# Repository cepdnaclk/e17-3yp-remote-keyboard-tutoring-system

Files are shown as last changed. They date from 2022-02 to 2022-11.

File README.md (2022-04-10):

# Remote Keyboard Tutoring System

[](https://youtu.be/UrKorkKD-kg)

## Table of Contents
  - [Remote Keyboard Tutoring System](#remote-keyboard-tutoring-system)
  - [Table of Contents](#table-of-contents)
  - [Problem Overview](#problem-overview)
  - [Already Existing Approaches](#already-existing-approaches)
  - [Our Solution](#our-solution)
  - [Solution Architecture](#solution-architecture)
  - [Backend](#backend)
  - [Hardware Functionalities](#hardware-functionalities)
  - [Planned Features](#planned-features)
  - [Security Aspects](#security-aspects)
  - [Proposed Timeline](#proposed-timeline)
  - [Estimated Budget](#estimated-budget)
  - [Feedback](#feedback)
  - [Related Links](#related-links)

## Problem Overview

Piano is the most admired musical instrument so far. Over 25% of the world population fancy playing it. Yet not everyone is fortunate to learn from the best. This has fabricated a vast difference in the skill level of people who are playing the piano. The reason would be that most of the experts in the field lives in either the western hemisphere or east Asia. Even local experts aren't scattered throughout the island. So most of them tend to make use of the online procedures to teach piano. The current online methods would be using a platform like zoom and an app that simulates what one plays from his instrument.  Or else the student self learns just using an online app or tutorials. This hasn't shown profound results since the teacher or the student has problems when showing what he's playing on the piano in real time. The accuracy of the app isn't acceptable and the relationship between the student and the teacher isn't sturdy like in a live class room. Following problems occur due to an absence of a well-established remote method to teach or lean piano.

* A piano player has to be subtle. Several skills like hand / eye coordination, finger patterns, timing should be handled precisely.

* If teacher uses the online video streaming method to show what he plays on his piano, he might have to use several accessories (Ex: One camera to show his hand coordination, one camera to show his postures, a quality mic).

* People with a great potential might give up due to current ineffective ways to learn piano / keyboard online or not having a professional piano player to learn from his current location of residence.

## Already Existing Approaches

When it comes to online piano tutoring apps there are many popular apps for self-learning. Some of the popular apps are:

* [Skoove](https://www.skoove.com/en)
* [Yousician](https://yousician.com/)
* [Simply piano](https://www.joytunes.com/simply-piano)
* [Online Pianist](https://www.onlinepianist.com/)

All of them uses simulated keyboards to show the notes that the leaner should play and most of them uses the phone mic to get inputs to the app and give feedback to the player. These aren’t very accurate at giving you feedback since they can’t accurately identify the notes just using the microphone. The above applications _do not focus on remote real-time teaching_.

However, there are systems called [Piano Player Systems](https://www.amromusic.com/player-piano-systems) (or self playing pianos) which sort of do implement the above mentioned functionality. One example would be the [PianoDisc Piano Player](https://pianodisc.com/). These systems are mainly based on Pianos and not Keyboard Synthesizers. Thus, not everyone is able to afford those. Even though these systems can be used for remote tutoring purpose, they are mainly designed for entertainment purpose.

## Our Solution

The solution we present is a web based system that can be attached to any keyboard synthesizer through a MIDI connector (Legacy or USB). Thus, the only requirement for the keyboard is MIDI support. Once our system is connected to the keyboard, the user can interactively learn, play or teach in combination with the web application that we provide. The user has to be logged in as either a typical user or an expert depending on the user's needs. Users can get connected to each other in the network and they can share their music with each other. Users can play shared music in their own keyboard and join to experts to learn remotely in real-time. The tutor can handle multiple students at a time. When the tutor plays on the keyboard, those notes will be displayed and played in the students keyboards simultaneously. Tutor can upload exercises and when a student plays incorrectly, the wrong key presses will be displayed to both the student and the tutor.

## Solution Architecture

Our system consists of two devices: the _Pocessing Unit_ and the _Visualizer Bar_ which is a composition of _Visualizer Blocks_.

Processing Unit             |  Visualizer Bar
:--------------------------:|:-------------------------:
|  

The **Processing Unit** handles all the data processing and remote communications. It has two MIDI interfaces (one for MIDI-in and the other for MIDI-out) as well as two USB-C ports. The other USB port is to connect the visualizer bar in.

The **Visualizer Bar** is where all the key press information will be displayed at. The bar has to be placed on the keyboard near the end where the key hinges are. We provide the visualizer bar as easy-to-connect blocks in order for our product to fit any kind of keyboard and to make our product portable. The three common keyboard sizes are 61-keys, 76-keys and 88-keys. Therefore, the blocks are such that it covers an octave. Since blocks might not cover the whole keyboard, we provide the visualizer bar as a whole for the most common keyboard sizes as well. The visualizer bar has a USB-C port at the right end to connect in to the processing unit. The visualizer blocks have magnetic ends to stay still when they're connected. Left end of a block has a female USB-C port and the right end has a male USB-C connection. The bar has RGB leds representing each key and they will lit according to the key presses.

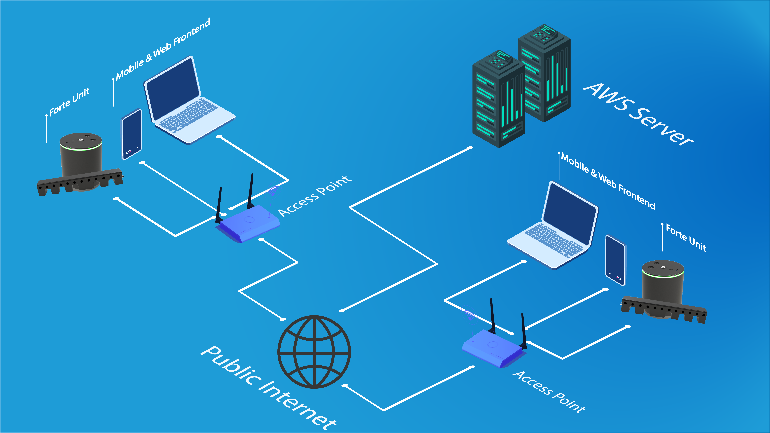
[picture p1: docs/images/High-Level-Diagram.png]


The above diagram shows an abstract diagram of how our system works.
Our solution consists of two main components: The Pocessing Unit and the Visualizer Bar 
The processing unit is connected to the keyboard via the MIDI interface and the processing unit is connected to the visualizer bar via a USB-C interface. The processing unit has inbuilt WI-FI as well as Bluetooth so the processing unit can directly connected to our server via a home router and exchange MIDI data with the server and with a another processing unit if they are connected in a same session. In order to communicate with the server we are going to implement a mobile as well as a web interface.

## Frontend

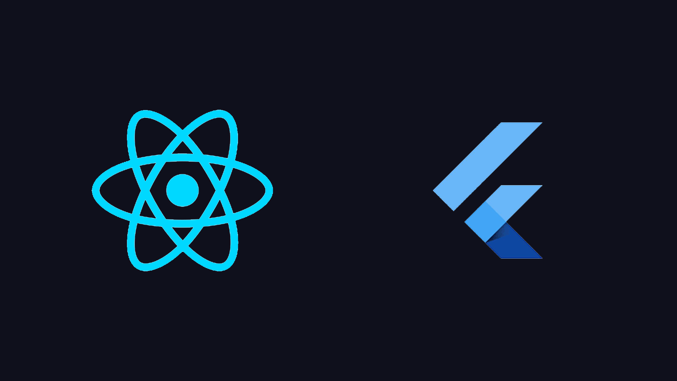
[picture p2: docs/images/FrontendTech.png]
Frontend-Technologies


For our frontend web platform would be implemented using React.js. React will assure a fast and easy development of the frontend since React provides lots of readymade components to use and React uses javascript it will be easier to coordinate with the backend as well. Other than that React apps can be made SEO friendly by making them server-side rendered rather than client-side rendered.
Our frontend mobile platform will be implemented using Flutter since it also provides a lot of components to use and Flutter performs well in a lot of mobile devices. Since Flutter uses Dart as the programming language we can use the same codebase for both ios and android applications.
[Click here](./web-app) to see what we have done up to now in the web frontend.
[Click here](./Mobile%20App/rkt_mobile) to see what we have done so far in the mobile frontend. 

## Backend

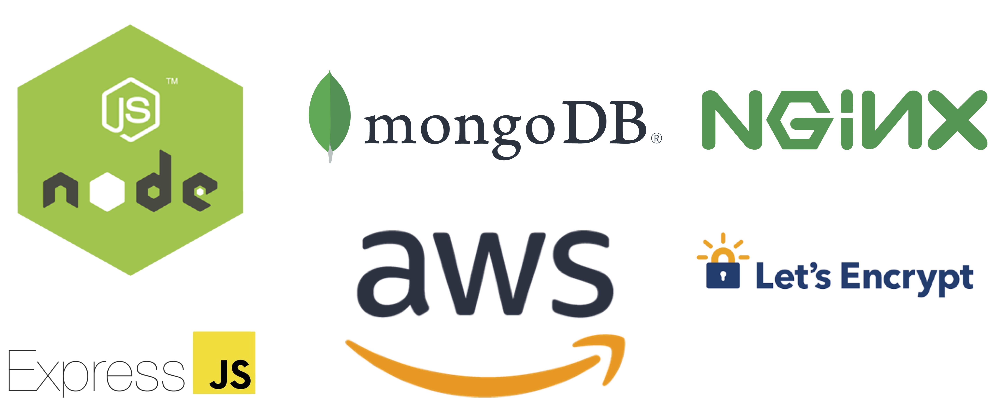
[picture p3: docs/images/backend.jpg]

Our backend computing platform would be Node.js along with express as the framework. It'll assist us in hadling multiple online requests and the working environment will be more effective and better-coordinated since javascript laguage is used in both frontend and backend development. MongoDB will be used as our database system. As the number of users for our product increase, it is very much practical to use MongoDB since it is very easy to scale up or down. MongoDB works on all types of cloud platforms. Since we'll be using aws to host our services MongoDB will be a great choice. NGINX is used as a reverse proxy so we can get access through http, https and Let's Encrypt is used to get free SSL certificates. All our backend services will be hosted using AWS services. An AWS EC2 instance is used run all the processes and AWS backup will be used to automate and manage backups. 

[click here](./server/src) to see what we have done so far.

## Hardware Functionalities

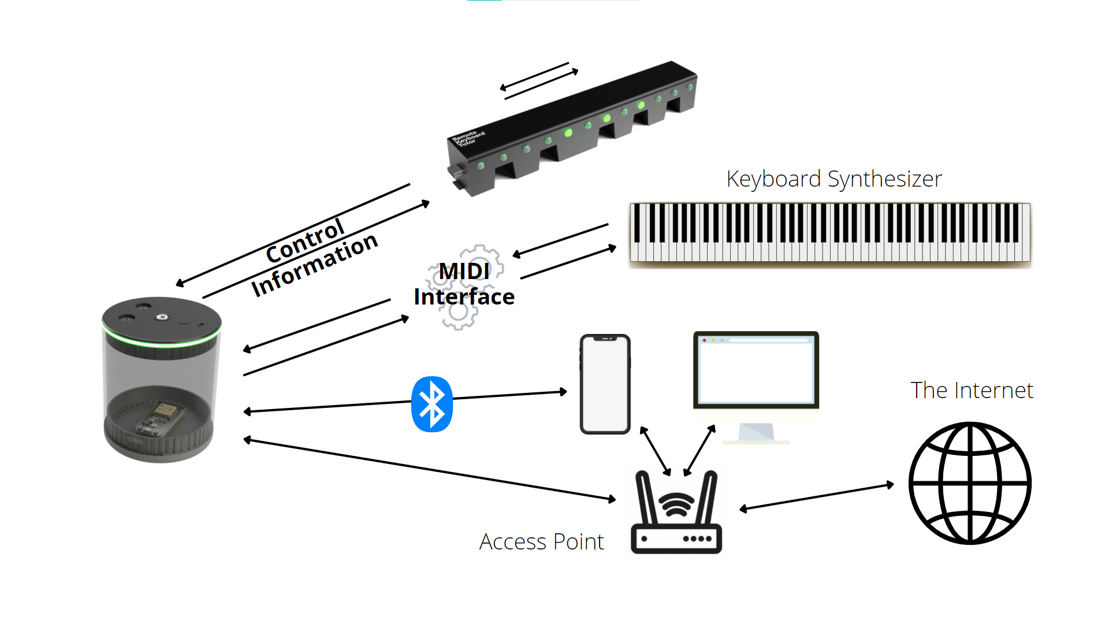
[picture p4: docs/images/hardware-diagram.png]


When it comes to hardware used in our embedded system, the brain of our processing unit is the **ESP32 Development board**. There are several reasons why we chose this board over other alternatives: built-in Wifi connectivity with 150Mbps data rate, integrated Bluetooth low energy (BLE) connectivity very small and compact board and the power consumption is less. As shown in the above high-level diagram, we need to have a MIDI interface in between the visualizer bar and the keyboard synthesizer for communicating with **MIDI messages** ([What is MIDI?](https://github.com/cepdnaclk/e17-3yp-remote-keyboard-tutoring-system/tree/main/Research/MIDI%20Technology)). The processing unit will be connected to Wifi as well as to the mobile phone via bluetooth. We use this BT connection for the offline helper as well as to authenticate to a Wifi router.

When MIDI messages arrive at the processing unit either from the user's keyboard or from remotely through the server, the microcontroller will process them and send control signals to the visualizer bar appropriately. The  communication between the visualizer bar and the processing unit will happen via an USB interface through a wired connection. The visualizer bar will also need to send signals to the processing unit because in order to light up the correct key on the keyboard, the processing unit needs to know the positional information of the particular visualizer block. So, before the user starts using the system he needs to do a very simple calibration procedure: play both the first note and the last note one after the other that the visualizer bar covers when the app prompts and thereafter the processing unit will memorize which block is where. In order to achieve this, the visualizer bar will also require a microcontroller. We will be using an arduino pro micro for this purpose.

## Planned Features

* Low latency real-time key press indication.
* Easy to setup / connect.
* The visualizer bar will be non-disturbing to the user and it will also add some aesthetics to the keyboard.
* The system will support any kind of non-standard keyboard as long as the keyboard has MIDI support.
* Students can easily find teachers available near their area.
* Classes can be scheduled through the application.
The web application allows teachers to upload exercises which will be played on student’s keyboard as MIDI so that the students can go along with and practise.
* Students can record what they’re playing and submit to the teacher in order to evaluate their work.
* An offline helper which can give assistance with the exercises.
* Efficient real-time Video & Audio Streaming for classes.
* Posture tracking for improving student's posture while playing.
* Finger tracking to check if the students are following the correct hand posture.

Current progress on implemented features can be seen [here](https://github.com/cepdnaclk/e17-3yp-remote-keyboard-tutoring-system/tree/main/web-app)

## Security Aspects

Cybersecurity of connected embedded system devices has always been important. Since our system also involves sharing private information through the internet like passwords and online payments, we have taken extra care to ensure the security of the system. The following diagram shows how we have designed our system to ensure the CIA triad.

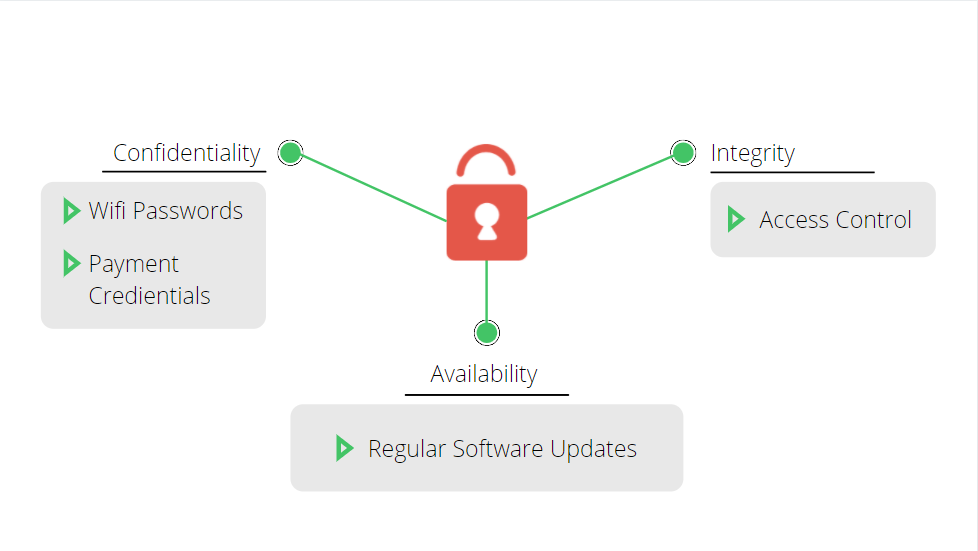
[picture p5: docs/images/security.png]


The following diagram shows our secure embedded system design process. The gray color path is the ideal embedded system design process that anyone would follow. In addition to that, we have added a security approach that'll happen in parallel with the embedded system design process. Starting from our concept of operations, we will do a threat analysis while collecting the functional requirements to analyze the potential attacks that the system may be subjected to when deployed. The next step is to specify how our demand measures the security requirements of the system. Once we have the security requirements, we will start developing the security approach after some rounds of evaluations.

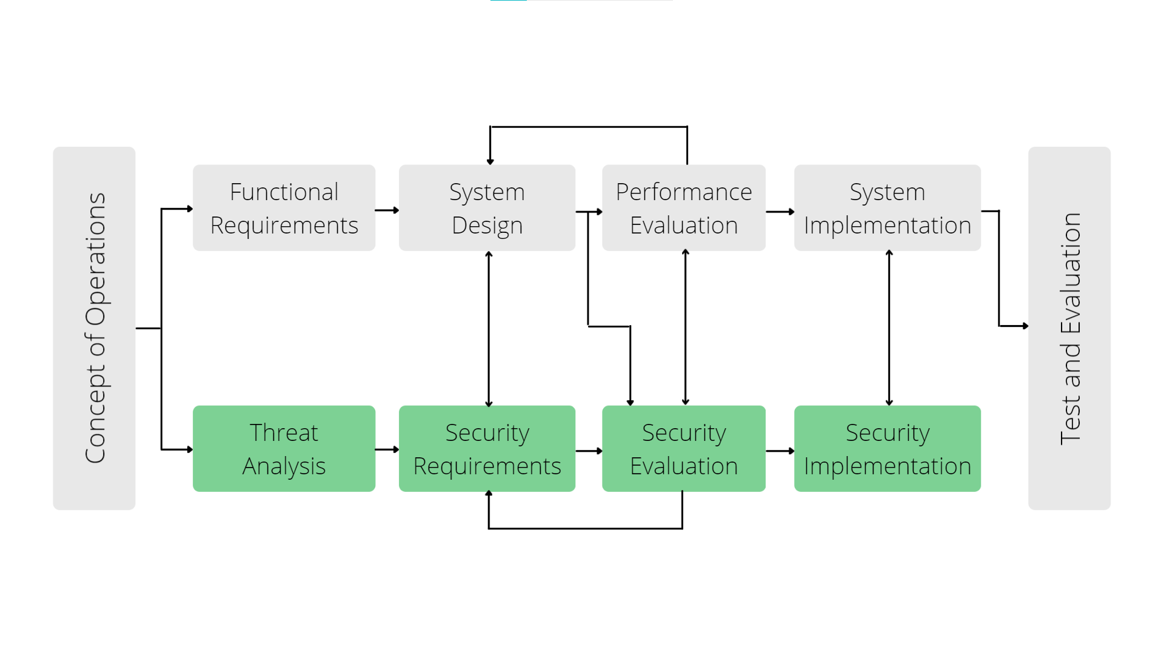
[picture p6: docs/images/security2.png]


## Proposed Timeline

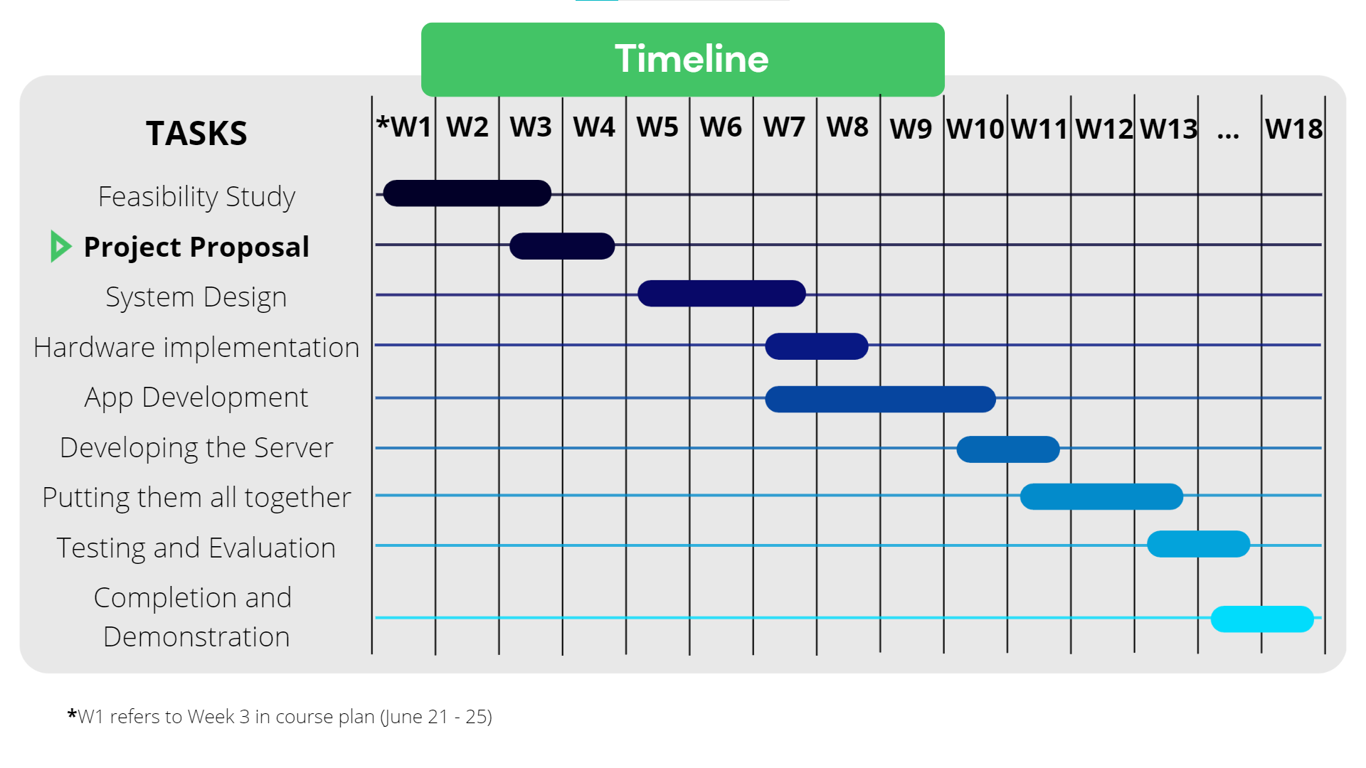
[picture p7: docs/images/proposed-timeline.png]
Proposed Timeline


## Estimated Budget

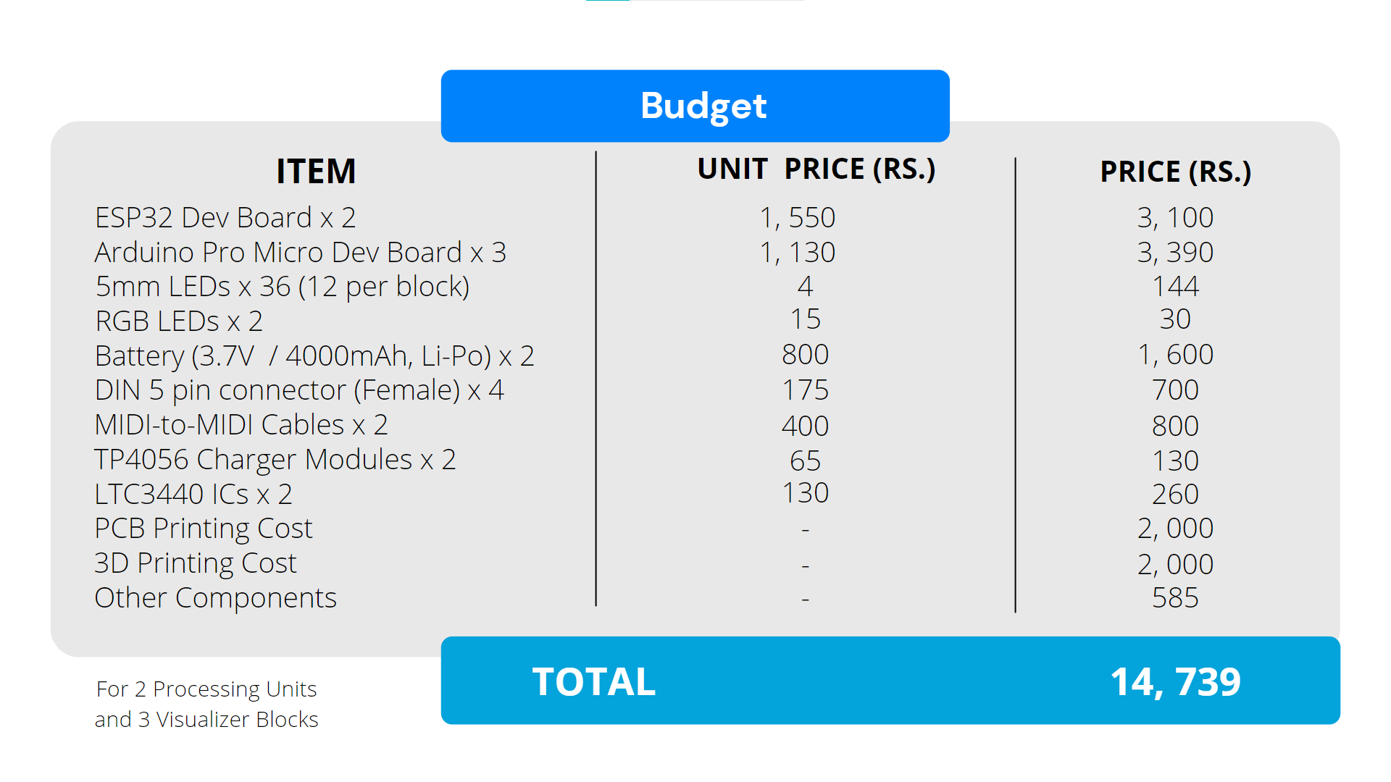
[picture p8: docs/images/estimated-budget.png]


## Feedback

✨ If you have any questions or suggestions for improvement regarding our project, feel free to share them [here](https://padlet.com/sathiiii/RKT_Discussion).✨

## Related Links

[University of Peradeniya](https://www.pdn.ac.lk/academics/academics.php/)

[Faculty of Engineering](http://eng.pdn.ac.lk/)

[Department of Computer Engineering](http://www.ce.pdn.ac.lk/)

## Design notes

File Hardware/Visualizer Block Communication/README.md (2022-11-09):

# Visualizer Block Communication

## Visualizer Block Schematic

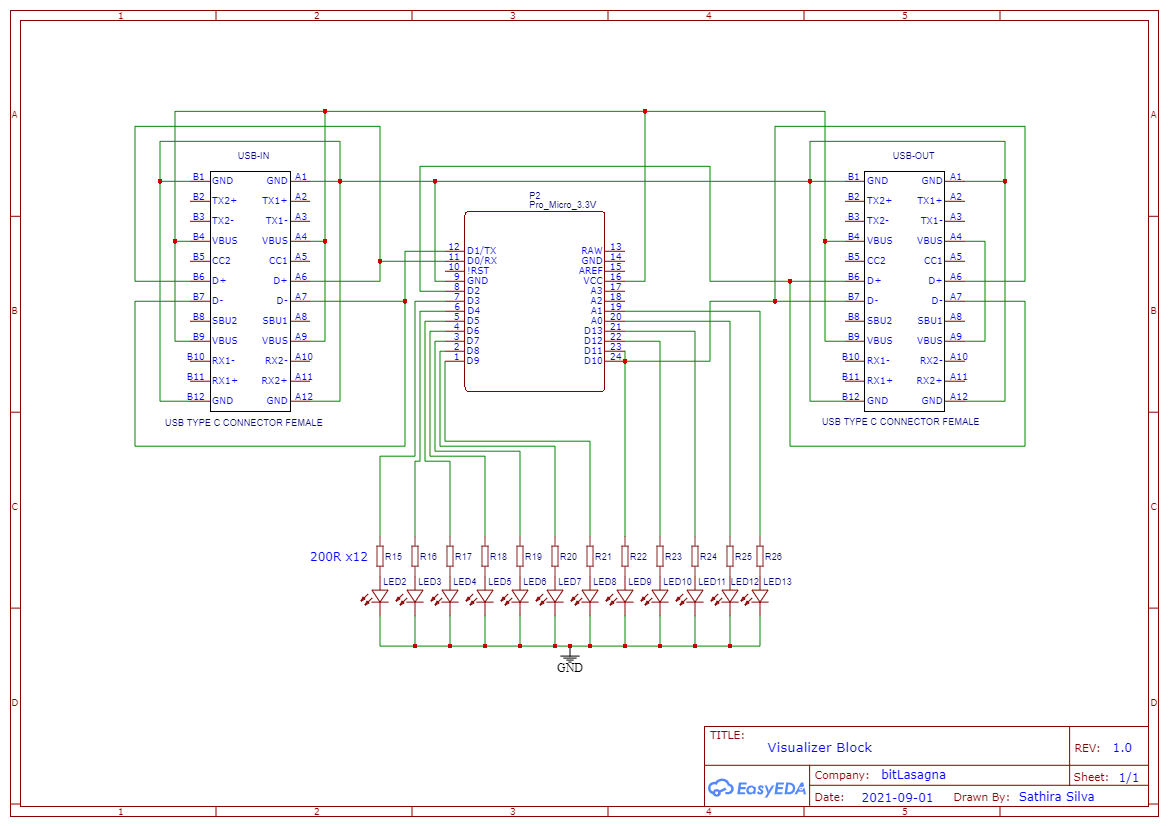
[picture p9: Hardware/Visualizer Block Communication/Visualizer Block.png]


All the operations in a Visualizer Block is handled by an **Arduino Pro Micro** inside. The reason for using an Arduino Pro Micro is that they come as two versions: 3.3V and 5V. Since the ESP32's working voltage is 3.3V, Arduino Pro Micro 3.3V will be compatible to communicate with it serially. Also, it consumes less power and the development board does not take much space. On the other hand, the serial port (pin 0 and pin 1) in Arduino Pro Micro is independent of the USB-Serial port that is used to communicate with PC. Therefore, we can use pin 0 and pin 1 for the Visualizer Block - Visualizer Block communication with no trouble since it won't interfere with the USB-Serial port.

The Arduino Pro Micro has 20 digital I/O pins. Therefore, it is more than enough to utilize 12 outputs for the 12 LEDs corresponding to the 12 different notes in an octave (C, C#, D, D#, E, F, F#, G, G#, A, Bb, B).

Unfortunately, the Pro Micro provides only one UART port. But we need two of them to communicate with each other. Therefore, we use the digital pins 3 as TX and 10 as RX with the **Arduino SoftwareSerial** library to replace the functionality.

## Communication

The communication between a Visualizer Block and another Visualizer Block or between a Visualizer Block and the processing unit is done **serially** via **UART communication protocol**.

UART, which stands for Universal Asynchronous Reception and Transmission, is a simple serial communication protocol that allows the host (Arduino Pro Micro or ESP32 in our case) to communicate with serial devices.

UART supports bidirectional, asynchronous and serial data transmission.

Before the UART device can send data, the transmitting device converts the data bytes to bits. After converting the data into bits, the UART device then splits them into **packets** for transmission. Each packet contains a start bit, a data frame, parity bit, and the stop bit. The data frame is usually 8 bits long. The following diagram shows an example data packet:



The following diagram shows how the data transmission and framing happens in UART communication protocol.

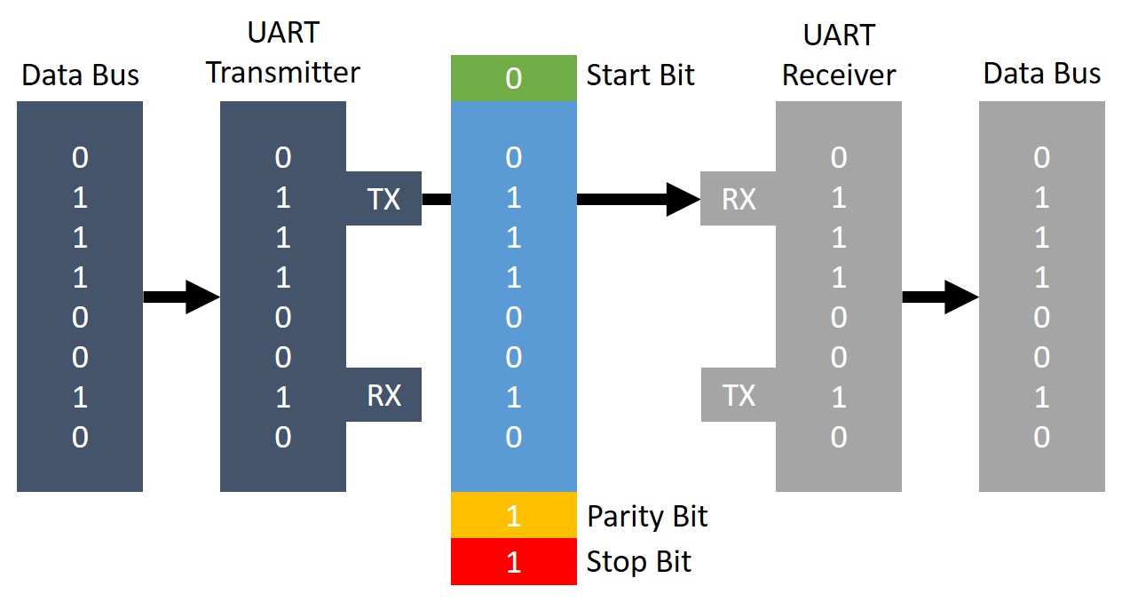
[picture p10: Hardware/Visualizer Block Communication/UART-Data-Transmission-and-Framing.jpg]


One advantage of UART is that only 2 wires are needed for the communication between master and slave device, because there is no need for a clock line and like SPI communication, there is also no slave select line. The 2 lines are: TX (transmission) and RX (reception).

### Our own communication protocol

The following diagram dipicts how the hardware communicates with each other.

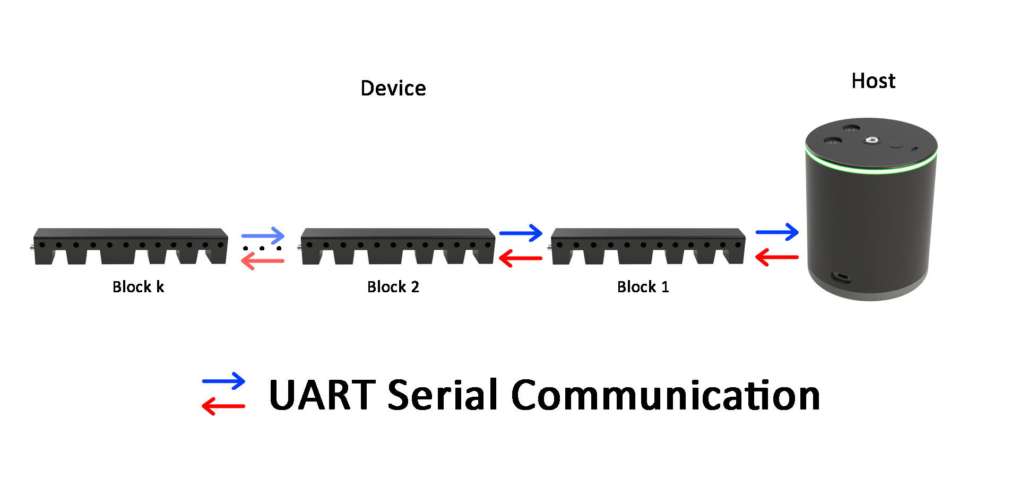
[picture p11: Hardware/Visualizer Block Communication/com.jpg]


We've made our own communication protocol to communicate with the Visualizer Blocks. The Processing Unit is referred to as the **Host** and the Visualizer Bar is referred to as the **Device**.

As shown in the above diagram, there are two types of communication: **Host-Device** communication and **Device-Device** communication. During data transmission, the sender will be the master and the reciever will the slave since in UART communication there'll always be 1 master and 1 slave. So, the transmissions are done in a **daisy chain** (several devices linked together serially) fashion.

When MIDI messages are recieved by the Processing Unit, it processes them and sends serial data packets to the appropriate Visualizer Block. The data packet won't arrive at the particular block directly, instead the packet will travel through all the blocks until the packet finds it's destination Visualizer Block.

Therefore, there's a need to define different kind of data packets (bit strings) that is responsible for different tasks. The reciever's id (or an address) and/or the sender's id also needs to be encapsulated in a data packet.

The types of packets we're using for host-device and device-device communication are as following:
1. Device notify packets.
2. Device discovery packets.
3. Host notify packets.
4. Control information packets.

To indicate which packet is which, we will include two bits (for now) of information to store the **action** of the packet.

<table>
  <tr>
    <th>action</th>
    <th>Description</th>
  </tr>
  <tr>
    <td>00</td>
    <td>Device Notify</td>
  </tr>
  <tr>
    <td>01</td>
    <td>Device Discovery</td>
  </tr>
  <tr>
    <td>10</td>
    <td>Host Notify</td>
  </tr>
  <tr>
    <td>11</td>
    <td>Control Information</td>
  </tr>
</table>

A packet in general will be as follows:

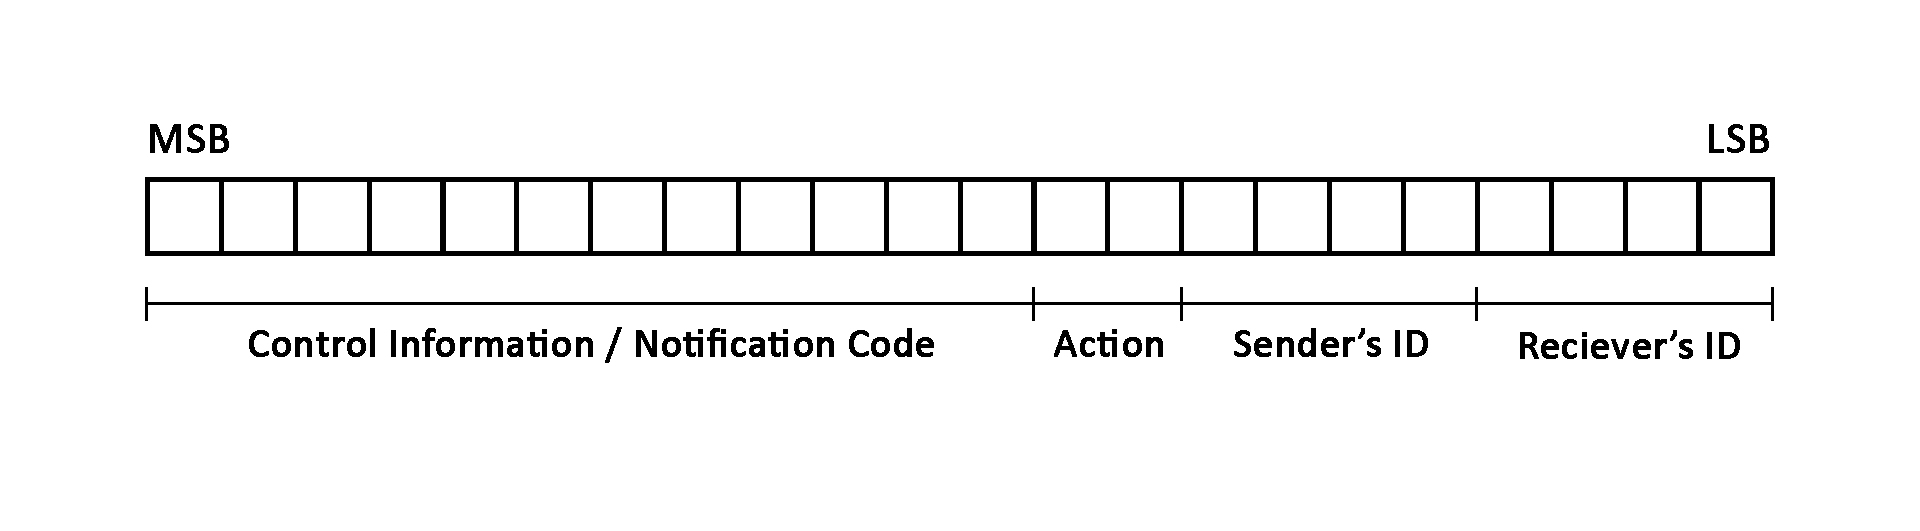
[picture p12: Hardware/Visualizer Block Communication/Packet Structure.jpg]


Note that the visualizer blocks will always send **Device Notify** packets indicating that it is communicating with another visualizer block unless it is the directly connected block to the processing unit. Otherwise, the visualizer block can send a **Host Notify** packet since it can directly communicate with the processing unit. However, if the Device Discover (which the following sections describe in detail) phase is not completed yet, the visualizer block that's directly connected to the processing unit will send a **Device Notify** packet to the host since the visualizer block doesn't know that it has a direct connection to the host, yet. This also makes the host to know which block is the directly connected one.

**When the processing unit is powered on**, it will wait until the visualizer bar to be connected. The processing unit waits for a **Device Notify: Connected** packet (i.e. until there's an available visualizer bar connection. When a visualizer block is connected, it sends a **Device Notify: Connected** packet to the device at the right side of it). The LED ring will flash periodically to indicate that the visualizer bar needs to be connected. When it is connected to the visualizer bar, the LED ring will be turned off to indicate that the **Device Discovery** is on progress. When the processing unit recieves a Device Notify: Connected packet, it sends a **Device Discovery** packet containing it's ID (zero) and the destination id (the visualizer block id) set to be 1 initially.

### The Device Discovery Phase

The device discovery happens as following:
1. The processing unit sends a device discovery packet containing the block_id (reciever's id) initialized to 0, to the visualizer bar. The sender's id will be zero to indicate that it's the processing unit that sends the packet.
2. The very first visualizer block that is directly connected to the processing unit will receive the packet and will assign the block_id to itself. Then it'll set the sender's id as the block_id that it just assigned, increment the block_id and will send another device discovery packet to the next visuzlier block that is connected to it.
3. So on and so forth this will happen until the packet reaches the last visualizer block. Because of the **Device Notify: Connected** packets that were initially sent. The last block knows that nothing is connected to the left side of it and thus it is the last block. Therefore, this block will send a **Host Notify: Discovery Finished** packet with sender's id being the final value of the block id (block id of the last visualizer block) and the reciever's id being zero back to the processing unit.

**Host Notify** packets won't be modified by any of the recieving devices and will be forwarded until the packet reaches the processing unit.

When the host recieves the **Host Notify: Discovery Finished** message, it is ready for the next stage: **Callibration**.

### Callibrating the Visualizer Bar

Callibrating pretty simple, the LED ring will flash twice periodically when the Device Discovery is finished, indicating that the user needs to press the first key that the first visualizer block (in terms of the block id, the last visualizer block) covers.

Then, the processing unit will map each key to each visualizer block and store those information. So, when a MIDI message arrives at the processing unit, it can process the message and find which block covers that particular key in the MIDI message and send the Control Information packet to that Visualizer Block.

**NOTE:** If the visualizer block positions have been changed, the user can recallibrate by tapping the command button twice on the processing unit.

After the callibration is done, the system is ready.

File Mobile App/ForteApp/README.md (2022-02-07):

# Forte App

## Getting Started

This project is a starting point for a Flutter application.

A few resources to get you started if this is your first Flutter project:

- [Lab: Write your first Flutter app](https://flutter.dev/docs/get-started/codelab)
- [Cookbook: Useful Flutter samples](https://flutter.dev/docs/cookbook)

For help getting started with Flutter, view our
[online documentation](https://flutter.dev/docs), which offers tutorials,
samples, guidance on mobile development, and a full API reference.

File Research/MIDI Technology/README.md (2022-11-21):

# What's MIDI?

- MIDI - Musical Instrument Digital Interface
- A standard protocol for communication between computers and musical instruments. 
- Sends series of **messages** which are intepretted by a MIDI instrument.

## MIDI messages
- Made up of an 8-bit **status byte** (or **command byte**) which is generally followed by 1 or 2 **data bytes**.
- Command byte: tells what type of message is being sent.
- Data bytes: actual data that is sent with the command byte.
- Two types of MIDI messages: *System messages*, *Channel messages*.

- Channel -> an independent path over which messages travel to their destination.
- A MIDI device has 16 channels.
- Channel messages -> apply to a specific channel, channel number is included in the status byte.
- Channel Messages may be further classified as being either *Channel Voice Messages*, or *Mode Messages*.
- Channel Voice Messages: carries musical performance data.

## Channel Voice Messages

Categories: Note On, Note Off, Polyphonic Key Pressure, Channel Pressure, Pitch Bend Change, Program Change, and the Control Change messages.

- MIDI **data bytes** range from 0 to 127 (MSB is always 0).
- MIDI **command byte** ranges from 128 to 255 (MSB is always 1).
- Two types of bytes are differentiated by the MSB.
- First half of the command byte (three bits after MSB) -> sets the type of command.
- Last half of the command byte -> sets the channel number.

## MIDI Commands



10000000 (128) = note off</br>
10010000 (144) = note on</br>
10100000 (160)  = aftertouch</br>
10110000 (176) = continuous controller</br>
11000000 (192) = patch change</br>
11010000 (208) = channel pressure</br>
11100000 (224) = pitch bend</br>

### Note On

- Sent when a key is pressed.
- Consists of two pieces of info: which key was pressed (**note**) and how fast it was pressed (**velocity**).
- **Note** is a number from 0 to 127. Middle C (C4) is 60.
- **Velocity** is a number from 0 to 127. Describes volume of the note.
(For some voices, different velocities create different **timbres**.)

### Note Off

- Sent when a key is released.
- Also contain **note** information to ensure that it is signalling the end of the right note.
- Sometimes a note off may contain velocity information too.

### Aftertouch

- The amount of pressure applied to a note.
- Sent when a key is pressed.
- Ranges from 0 to 127.

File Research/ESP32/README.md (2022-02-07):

# ESP-32 Development Board

[Official Documentation](https://docs.espressif.com/projects/esp-idf/en/latest/esp32/)

## Introduction

ESP32 is a system on a chip that integrates the following features:

* Wi-Fi (2.4 GHz band, 150.0 Mbps data rate with HT40)
* Bluetooth (BLE - Bluetooth Low Energy and Bluetooth Classic)
* Dual high performance Xtensa® 32-bit LX6 CPU cores  running at 160 or 240 MHz
* Ultra Low Power co-processor
* Flash memory (4 MB)
* 32-bit SRAM
* Multiple peripherals
* Security: hardware accelerators for AES and SSL/TLS
* Arduino IDE compatible
* Low Power: ensures that you can still use ADC conversions, for example, during deep sleep

Powered by *40 nm technology*, ESP32 provides a robust, highly integrated platform, which helps meet the continuous demands for **efficient power usage**, **compact design**, **security**, **high performance**, and **reliability**.

The ESP32 can be programmed in different programming environments, including:

* Arduino IDE
* Espressif IDF (IoT Development Framework)
* Micropython
* JavaScript
* LUA

Espressif provides basic hardware and software resources to help application developers realize their ideas using the ESP32 series hardware. The software development framework by Espressif is intended for development of Internet-of-Things (IoT) applications with Wi-Fi, Bluetooth, power management and several other system features.

## ESP32 Peripherals

The ESP32 peripherals include:

* 18 Analog-to-Digital Converter (ADC) channels
* 3 SPI interfaces
* 3 UART interfaces
* 2 I2C interfaces
* 16 PWM output channels
* 2 Digital-to-Analog Converters (DAC)
* 2 I2S interfaces
* 10 Capacitive sensing GPIOs

The ADC (analog to digital converter) and DAC (digital to analog converter) features are assigned to specific static pins. However, you can decide which pins are UART, I2C, SPI, PWM, etc – you just need to assign them in the code. This is possible due to the ESP32 chip’s multiplexing feature.

Although you can define the pins properties on the software, there are pins assigned by default as shown in the following figure (this is an example for the ESP32 DEVKIT V1 DOIT board with 36 pins – the pin location can change depending on the manufacturer).



Additionally, there are pins with specific features that make them suitable or not for a particular project. The following table shows what pins are best to use as inputs, outputs and which ones you need to be cautious.

The pins highlighted in green are OK to use. The ones highlighted in yellow are OK to use, but you need to pay attention because they may have an unexpected behavior mainly at boot. The pins highlighted in red are not recommended to use as inputs or outputs.

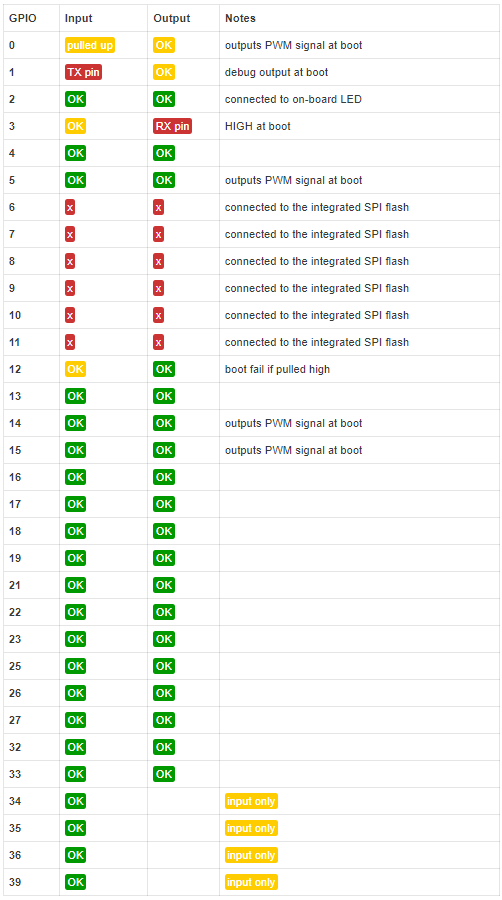
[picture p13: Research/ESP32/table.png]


GPIOs 34 to 39 are GPIs – input only pins. These pins don’t have internal pull-up or pull-down resistors. They can’t be used as outputs, so use these pins only as inputs:
* GPIO 34
* GPIO 35
* GPIO 36
* GPIO 39

## Power Requirements

The ESP32 Board operates between 2.2V to 3.6V. But we supply 5V from Micro-USB port. For 3.3V there is already an LDO voltage regulator to keep the voltage steady at 3.3V. ESP32 can be powered using Micro USB port and VIN pin (External Supply Pin).

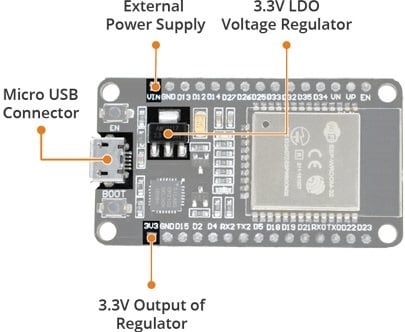
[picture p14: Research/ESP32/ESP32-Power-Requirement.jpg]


The power required by ESP32 is 600mA, as ESP32 pulls as much as 250mA during RF transmissions. During boot or wifi operation it’s drawing more than 200mA current. Thus supply power from Micro-USB Cable is not enough for ESP32 Board when we are adding multiple sensors or modules to the Board. This is because Computer USB port can provide less than 500mA of current.

## ESP-IDF (IoT Development Framework)

ESP-IDF is Espressif’s open-source official IoT Development Framework for the ESP32 series. It provides a self-sufficient SDK for any generic application development on these platforms, using programming languages such as C and C++. ESP-IDF supports a large number of software components, including RTOS, peripheral drivers, networking stack, various protocol implementations, and helpers for common application use-cases.

The framework also consists security of features such as hardware-backed security features, such as flash encryption and secure boot, cryptographic accelerator support for RSA, SHA and AES, libsodium and micro-ecc cryptographic libraries.

ESP-IDF supports IDEs such as Visual Studio Code ([Visual Studio Code Extension](https://github.com/espressif/vscode-esp-idf-extension), [Quick User Guide for the ESP-IDF VS Code Extension](https://youtu.be/Lc6ausiKvQM)) and Eclipse ([Eclipse IDE plugin](https://github.com/espressif/idf-eclipse-plugin)).

## ESP-IDF vs Arduino-ESP32

Arduino-ESP32 library is just a wrapper around the esp-idf mainly simplifying things and making it integrated with the design paradigms of arduino as a whole.

One can use the arduino version for the same reason that he would use arduino as a whole, namely for its low barrier to entry, extensive ecosystem/support, and ease of use. But he's not going to get the best performance, have the most maintainable/extensible code, or be able to take full advantage of the peripherals.

Firstly, arduino kind of pushes you in the wrong direction for serious embedded development, artificially confining you to a **setup and loop function**, when in reality it should be more focused on **compartmentalization of function into a task based application**. This is essentially what arduino-esp32 does under the hood, but you wouldn't know unless started to look into the idf yourself.

Secondly, being able to work directly with the idf means that you can actually understand errors that you get when you start combining peripherals or calling idf functions. You can call idf functions in arduino-esp32, but it is much easier to directly use the idf, be familiar with the api reference, and work directly with the source than having to translate everything through the wrapper functions when debugging something.

Thirdly, the idf runs **freeRTOS (free Real-Time Operating System)** (an operating system that runs code as **tasks**) which is pretty widespread in embedded systems, so the techniques and knowledge you gain will translate pretty well to other MCUs if you ever work with any others. This is where the idea of having **tasks and message passing between tasks** as opposed to a "**superloop**" comes from. You could do a super loop just as well in freeRTOS, but it is really designed to be more task based. Further, the idf has the design pattern of components which allow you to split off functionality into their little compartments, allowing large projects to be much easier to organize.

[~source](https://www.reddit.com/r/esp32/comments/dk3rsn/why_idf_vs_arduino_ide/)

## FreeRTOS Architecture

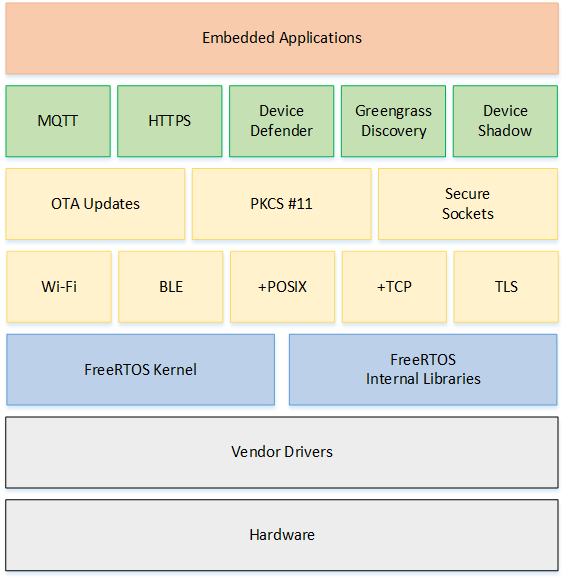
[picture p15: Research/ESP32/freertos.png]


## FreeRTOS Kernel Fundamentals

The Espressif Internet Development Framework (ESP-IDF) uses FreeRTOS to make better use of the two high speed processors and manage the numerous built-in peripherals. It is done by creating tasks.

The FreeRTOS kernel provides,
* A multitasking scheduler.
* Multiple memory allocation options (including the ability to create completely statically-allocated systems).
* Intertask coordination primitives, including task notifications, message queues, multiple types of semaphore, and stream and message buffers.

The FreeRTOS kernel is designed to be small, simple, and easy to use. A typical RTOS kernel binary image is in the range of 4000 to 9000 bytes.

### Kernel Memory Allocation

The RTOS kernel needs RAM each time a task, queue, or other RTOS object is created. The RAM can be allocated:

* Statically at compile time.
* Dynamically from the RTOS heap by the RTOS API object creation functions.

When RTOS objects are created dynamically, using the standard C library malloc() and free() functions is not always appropriate for a number of reasons:

* They might not be available on embedded systems.
* They take up valuable code space.
* They are not typically thread-safe.
* They are not deterministic.

For these reasons, FreeRTOS keeps the memory allocation API in its **portable layer**. The portable layer is outside of the source files that implement the core RTOS functionality, so you can provide an application-specific implementation appropriate for the real-time system you're developing. When the RTOS kernel requires RAM, it calls pvPortMalloc() instead of malloc(). When RAM is being freed, the RTOS kernel calls vPortFree() instead of free().

### Application Memory Management

When applications need memory, they can allocate it from the FreeRTOS heap. FreeRTOS offers several heap management schemes that range in complexity and features. You can also provide your own heap implementation.

The FreeRTOS kernel includes five heap implementations:

**heap_1**
Is the simplest implementation. Does not permit memory to be freed.

**heap_2**
Permits memory to be freed, but not does coalesce adjacent free blocks.

**heap_3**
Wraps the standard malloc() and free() for thread safety.

**heap_4**
Coalesces adjacent free blocks to avoid fragmentation. Includes an absolute address placement option.

**heap_5**
Is similar to heap_4. Can span the heap across multiple, non-adjacent memory areas.

## Hello World

The following is the structure of ESP-IDF:

>+--esp-idf<br>
&nbsp;&nbsp;&nbsp;&nbsp;	|<br>
&nbsp;&nbsp;&nbsp;&nbsp;	+ - - components<br>
&nbsp;&nbsp;&nbsp;&nbsp;	|<br>
&nbsp;&nbsp;&nbsp;&nbsp;	+ - - docs<br>
&nbsp;&nbsp;&nbsp;&nbsp;	|<br>
&nbsp;&nbsp;&nbsp;&nbsp;	+ - - examples<br>
&nbsp;&nbsp;&nbsp;&nbsp;	|<br>
&nbsp;&nbsp;&nbsp;&nbsp;	+ - - make<br>
&nbsp;&nbsp;&nbsp;&nbsp;	|<br>
&nbsp;&nbsp;&nbsp;&nbsp;	+ - - tools<br>

The components directory holds all the 'C' code for the ESP32. It contains all the **components** that make up the ESP32. It includes Drivers for numerous peripherals, the bootloader, bt(bluetooth), freeRTOS etc.

### The Includes

```C
#include <stdio.h>
#include "freertos/FreeRTOS.h"
#include "freertos/task.h"
#include "esp_system.h"
#include "esp_log.h"
```

* freertos/FreeRTOS.h : Inclusion of this sets configuration required to run freeRTOS on ESP32.
* freertos/task.h: The tasks as you can guess provide the multitasking functionality.
* esp_system.h: This inclusion configures the peripherals in the ESP system. Think of it as system initialization. It's like setting up all the components of your bike, before you could fire the engine!
* esp_log.h: This is the logging library. It's used to log information to the serial port.

### The main() function

Unlike normal FreeRTOS tasks (or embedded C main functions), the **app_main** task is allowed to return. If this happens, The task is cleaned up and the system will continue running with other RTOS tasks scheduled normally. Therefore, it is possible to implement app_main as either a function that creates other application tasks and then returns, or as a main application task itself. app_main is called from a task called main_task spawned in cpu_start.c.

```C
void app_main()
{
    nvs_flash_init();
    xTaskCreate(&hello_task, "hello_task", 2048, NULL, 5, NULL);
}
```

* **Initialize Flash: nvs_flash_init()**: Non-volatile storage (NVS) library is designed to store key-value pairs in flash. This API initialises the default NVS partition.
* **xTaskCreate**: Creates a new task and adds it to the list of tasks that are ready to run. Following is the function prototype:
<br>BaseType_t xTaskCreate(TaskFunction_t pvTaskCode,
&nbsp;&nbsp;&nbsp;&nbsp;&nbsp;&nbsp;&nbsp;&nbsp;const char * const pcName,
&nbsp;&nbsp;&nbsp;&nbsp;&nbsp;&nbsp;&nbsp;&nbsp;configSTACK_DEPTH_TYPE usStackDepth,
&nbsp;&nbsp;&nbsp;&nbsp;&nbsp;&nbsp;&nbsp;&nbsp;void *pvParameters,
&nbsp;&nbsp;&nbsp;&nbsp;&nbsp;&nbsp;&nbsp;&nbsp;UBaseType_t uxPriority,
&nbsp;&nbsp;&nbsp;&nbsp;&nbsp;&nbsp;&nbsp;&nbsp;TaskHandle_t *pxCreatedTask);
<br>**pvTaskCode**: Pointer to the task entry function.
<br>**pcName**: A descriptive name for the task. This is mainly used to facilitate debugging, but can also be used to obtain a task handle.
<br>**usStackDepth**: The number of words (not bytes!) to allocate for use as the task's stack. For example, if the stack is 16-bits wide and usStackDepth is 100, then 200 bytes will be allocated for use as the task's stack. As another example, if the stack is 32-bits wide and usStackDepth is 400 then 1600 bytes will be allocated for use as the task's stack.
<br>**pvParameters**: A value that is passed as the paramater to the created task. If pvParameters is set to the address of a variable then the variable must still exist when the created task executes - so it is not valid to pass the address of a stack variable.
<br>**uxPriority**: The priority at which the created task will execute.
<br>**pxCreatedTask**: Used to pass a handle to the created task out of the xTaskCreate() function. pxCreatedTask is optional and can be set to NULL.

### The hello_task()

The function that is called from the task created above is a simple function as shown below. It simply prints the string to the UART. The Print stream is configured to the UART0 of the ESP32.

```C
void hello_task(void *pvParameter)
{
    printf("Hello world!\n");
    for (int i = 10; i >= 0; i--) {
        printf("Restarting in %d seconds...\n", i);
        // Delay a task for a given number of ticks.
        vTaskDelay(1000 / portTICK_RATE_MS);
    }
    printf("Restarting now.\n");
    fflush(stdout);
    // Software restart.
    esp_restart();
}
```

### The Complete Code

```C
#include <stdio.h>
#include "freertos/FreeRTOS.h"
#include "freertos/task.h"
#include "esp_system.h"
 
void hello_task(void *pvParameter)
{
    printf("Hello world!\n");
    for (int i = 10; i >= 0; i--) {
        printf("Restarting in %d seconds...\n", i);
        vTaskDelay(1000 / portTICK_RATE_MS);
    }
    printf("Restarting now.\n");
    fflush(stdout);
    esp_restart();
}
 
void app_main()
{
    nvs_flash_init();
    xTaskCreate(&hello_task, "hello_task", 2048, NULL, 5, NULL);
}
```

## Multitasking: Hello World with Blink

It is easy to accomplish that using the RTOS. The code below, creates two tasks. It can be thought of as these are two infinite (while) loops. _Whenever one enters delay state (vTaskDelay function), the other runs and vice-versa_. Since we are slow and ESP32 is fast, it switches between the tasks numerous times and we see both the tasks happening simultaneously.

```C
#include <stdio.h>
#include "freertos/FreeRTOS.h"
#include "freertos/task.h"
#include "esp_system.h"
// Allows to manage General Purpose I/O pins via simple and portable APIs.
#include "driver/gpio.h"
#include "nvs_flash.h"

#define BLINK_GPIO 2
 
void hello_task(void *pvParameter)
{
	while(1)
	{
	    printf("Hello world!\n");
	    vTaskDelay(100 / portTICK_RATE_MS);
	}
}

void blinky(void *pvParameter)
{
    gpio_pad_select_gpio(BLINK_GPIO);
    /* Set the GPIO as a push/pull output */
    gpio_set_direction(BLINK_GPIO, GPIO_MODE_OUTPUT);
    while(1) {
        /* Blink off (output low) */
        gpio_set_level(BLINK_GPIO, 0);
        vTaskDelay(1000 / portTICK_RATE_MS);
        /* Blink on (output high) */
        gpio_set_level(BLINK_GPIO, 1);
        vTaskDelay(1000 / portTICK_RATE_MS);
    }
}
 
void app_main()
{
    nvs_flash_init();
    xTaskCreate(&hello_task, "hello_task", 2048, NULL, 5, NULL);
    xTaskCreate(&blinky, "blinky", 512,NULL,5,NULL );
}
```

On FreeRTOS, tasks have an assigned priority which the scheduler uses to decide which task will run. High priority tasks ready to run will have preference over lower priority tasks, which means that as long as a higher priority task can run, a lower priority task will not have the CPU.

## Utilizing multiple cores

FreeRTOS tasks can be pinned to a specific core too. Note that, when we create a task with the xTaskCreate function, we are not specifying any particular core for it to run. So, FreeRTOS will run the task on the core that is free.

To know in which core a task is running, the **xPortGetCoreID()** function can be used.

Tasks can be pinned to a specific core using the **vTaskCreatePinnedToCore** function. This function takes exactly the same arguments of the xTaskCreate and an additional argument at the end to specify the core where the task should run.

```C
xTaskCreatePinnedToCore(
                    coreTask,   /* Function to implement the task */
                    "coreTask", /* Name of the task */
                    2048,       /* Stack size in words */
                    NULL,       /* Task input parameter */
                    0,          /* Priority of the task */
                    NULL,       /* Task handle. */
                    taskCore);  /* Core where the task should run */
```

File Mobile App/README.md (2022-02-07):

# forté Mobile App

## What we have done so far

These are the functions that we have added upto now to the the forté mobile app.

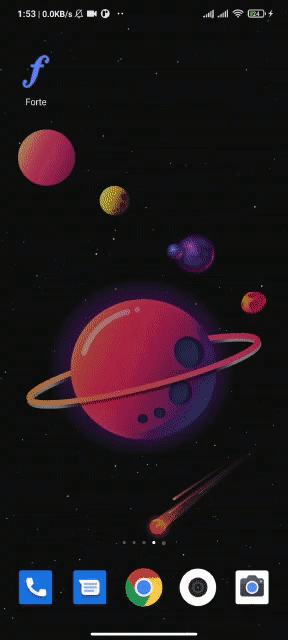
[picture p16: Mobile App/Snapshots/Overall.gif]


### ESP Provisioning



More details about esp provisioning can be found [here.](https://docs.espressif.com/projects/esp-idf/en/latest/esp32/api-reference/provisioning/wifi_provisioning.html)

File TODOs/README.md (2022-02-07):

# TODO List

Please make sure to update the list and mark the finished tasks.

- [x] Finish the repo documentation (initial).
- [x] Update the website information (initial).
- [x] Add a timeline section to the website such that our completed milestone can be displayed there.
- [ ] **First testing: Arduino MIDI read / write test.**
- [x] Update repo documentation: Solution Architecture.
- [x] Update repo documentation: Data flow + Generation of data + Visualizations.
- [x] Update repo documentation: Hardware functionalities.
- [x] Update repo documentation: Security aspects.
- [x] Update website: Add dropdown to navbar.
- [x] Update website: Data flow + Generation of data.
- [x] Update website: UI designs (placeholders).
- [x] Update website: Features (Each with placeholders for descriptions + diagrams).
- [x] Update website: Research findings <--- MIDI Technology + MIDI-to-sheetmusic.
- [x] Hardware functionalities, Security aspects.
- [x] Update repo/website documentation: Budget.
- [x] Update repo/website documentation: Timeline.
- [x] Building 3D models for Processing Unit and Visualizer Bar.
- [ ] **Research about Sheet Music reading, writing inside Web App and Mobile App + connect them to MIDI input / output.**
- [x] Short Introductory Video clip.
- [x] UI design for the Web platform.
- [x] UI design for the mobile app.
- [ ] Frontend implementation of the Web platform.
- [ ] Frontend implementation of the mobile app.
- [x] **EPS32 Wi-Fi Test**
- [ ] **EPS32 BT Test**
- [x] Build Schematics for Processing Unit.
- [x] Create Database Schemata -> Tutor | Student.
- [x] Research about back-end technologies.
- [x] Research about network technologies and protocols.

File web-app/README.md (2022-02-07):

# forté Web Application

## What we have done so far...

### Routing plan for the website

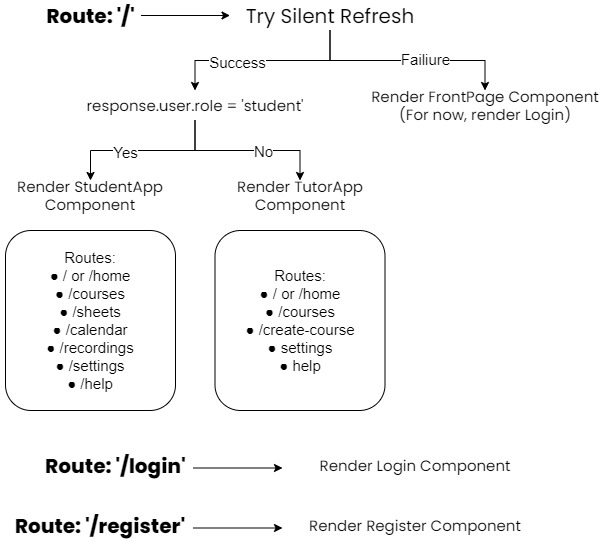
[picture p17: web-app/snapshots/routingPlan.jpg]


### Login Page

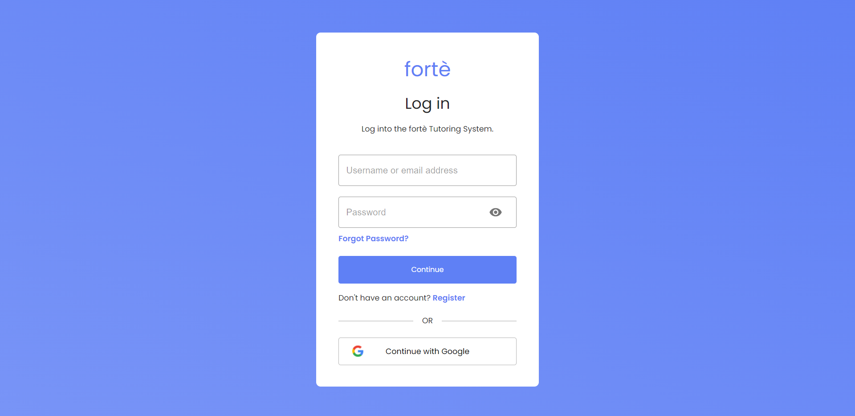
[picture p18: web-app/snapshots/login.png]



### Registration Page

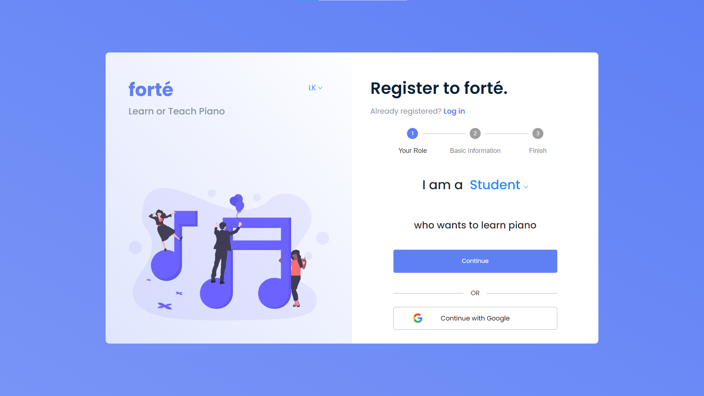
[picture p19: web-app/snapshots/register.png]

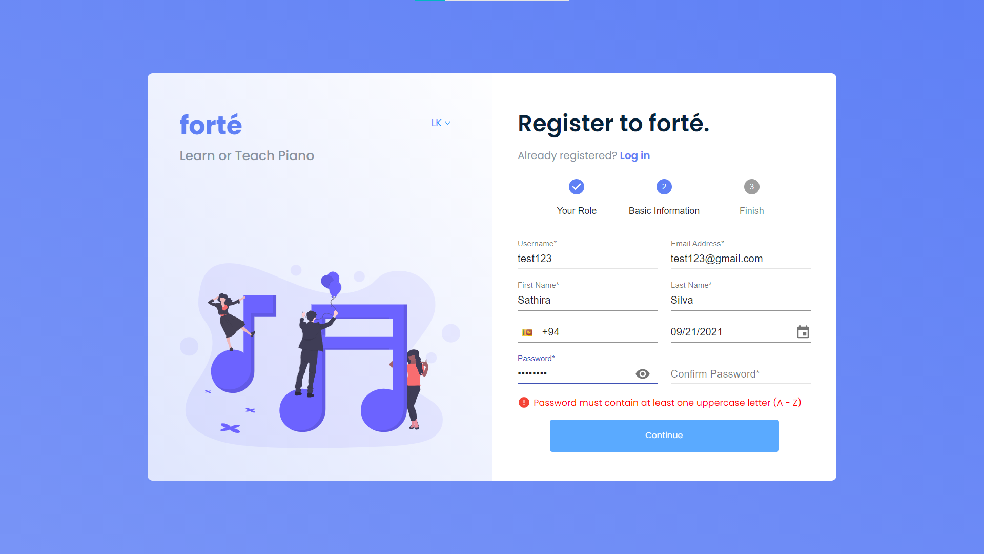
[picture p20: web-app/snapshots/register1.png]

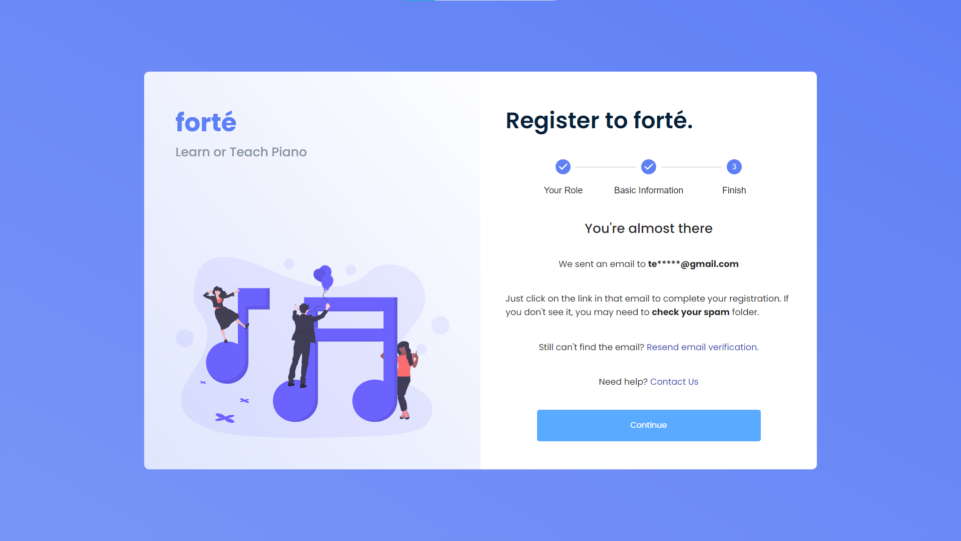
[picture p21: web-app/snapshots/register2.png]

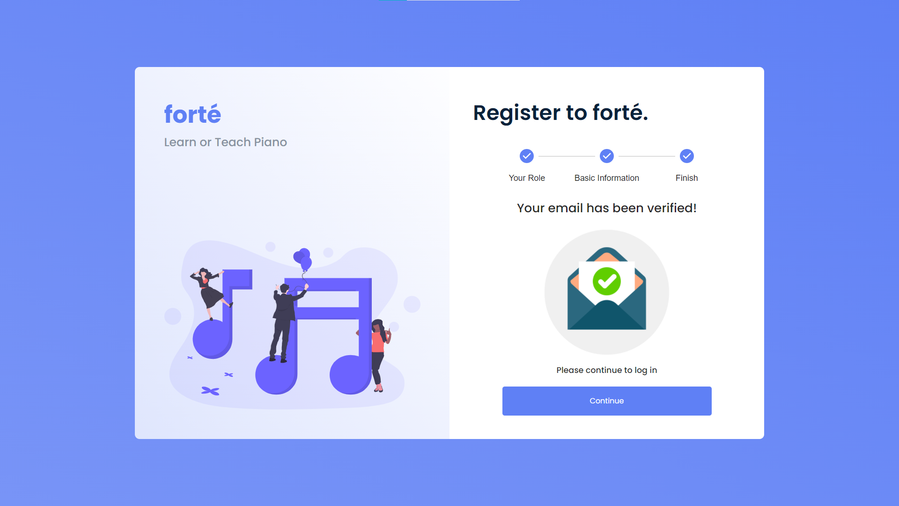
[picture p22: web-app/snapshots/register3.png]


### Student | Tutor App (Still in progress)

App features:

Prompt user to upload an avatar on the first use:
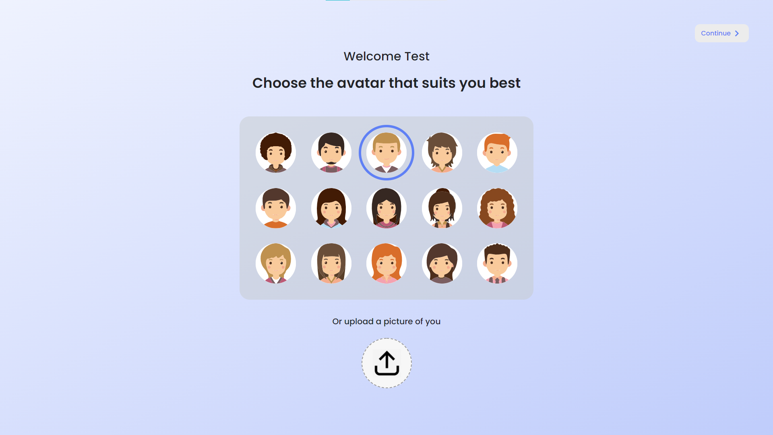
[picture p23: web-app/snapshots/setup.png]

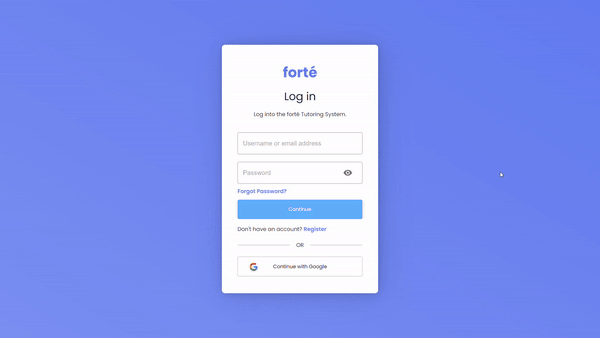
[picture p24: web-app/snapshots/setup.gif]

Course View (Tutor):

Course View (Student):

Creating a Course (Tutor):
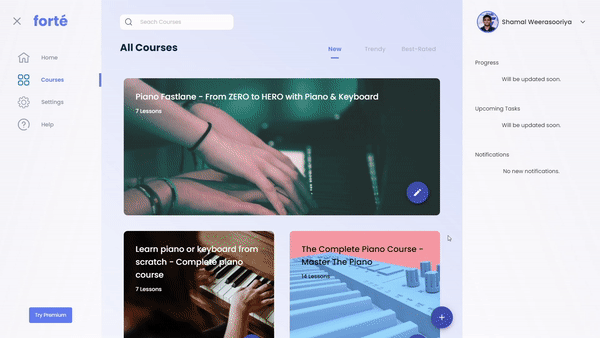
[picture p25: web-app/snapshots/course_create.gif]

Idle timeout:
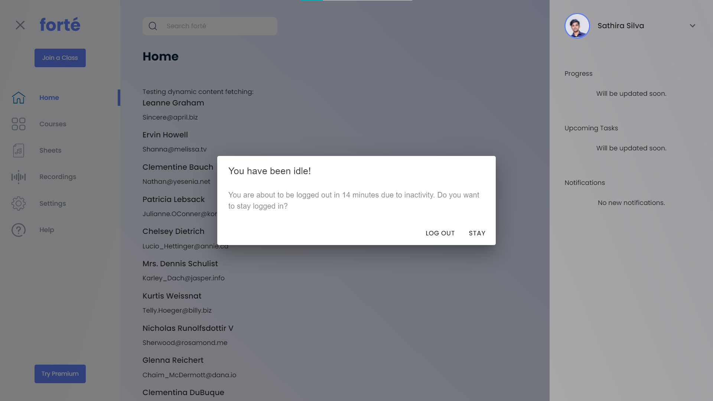
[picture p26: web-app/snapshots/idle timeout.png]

Classroom (Still in Progress):
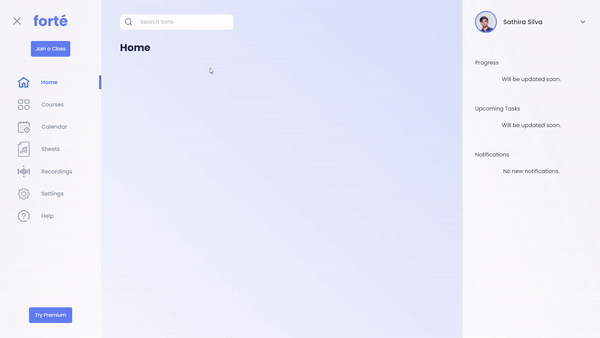
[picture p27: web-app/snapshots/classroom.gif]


This project was bootstrapped with [Create React App](https://github.com/facebook/create-react-app).

## Available Scripts for the Contributors

In the project directory, run:

### `npm install`

First run the above command to install all the dependencies.

### `npm start`

This command will run the app in the development mode.\
Open [http://localhost:3000](http://localhost:3000) to view it in the browser.

The page will reload if you make edits.\
You will also see any lint errors in the console.

### `npm test`

Launches the test runner in the interactive watch mode.\
See the section about [running tests](https://facebook.github.io/create-react-app/docs/running-tests) for more information.

### `npm run build`

Builds the app for production to the `build` folder.\
It correctly bundles React in production mode and optimizes the build for the best performance.

The build is minified and the filenames include the hashes.\
Your app is ready to be deployed!

See the section about [deployment](https://facebook.github.io/create-react-app/docs/deployment) for more information.

### `npm run eject`

**Note: this is a one-way operation. Once you `eject`, you can’t go back!**

If you aren’t satisfied with the build tool and configuration choices, you can `eject` at any time. This command will remove the single build dependency from your project.

Instead, it will copy all the configuration files and the transitive dependencies (webpack, Babel, ESLint, etc) right into your project so you have full control over them. All of the commands except `eject` will still work, but they will point to the copied scripts so you can tweak them. At this point you’re on your own.

You don’t have to ever use `eject`. The curated feature set is suitable for small and middle deployments, and you shouldn’t feel obligated to use this feature. However we understand that this tool wouldn’t be useful if you couldn’t customize it when you are ready for it.

## Learn More

You can learn more in the [Create React App documentation](https://facebook.github.io/create-react-app/docs/getting-started).

To learn React, check out the [React documentation](https://reactjs.org/).

### Code Splitting

This section has moved here: [https://facebook.github.io/create-react-app/docs/code-splitting](https://facebook.github.io/create-react-app/docs/code-splitting)

### Analyzing the Bundle Size

This section has moved here: [https://facebook.github.io/create-react-app/docs/analyzing-the-bundle-size](https://facebook.github.io/create-react-app/docs/analyzing-the-bundle-size)

### Making a Progressive Web App

This section has moved here: [https://facebook.github.io/create-react-app/docs/making-a-progressive-web-app](https://facebook.github.io/create-react-app/docs/making-a-progressive-web-app)

### Advanced Configuration

This section has moved here: [https://facebook.github.io/create-react-app/docs/advanced-configuration](https://facebook.github.io/create-react-app/docs/advanced-configuration)

### Deployment

This section has moved here: [https://facebook.github.io/create-react-app/docs/deployment](https://facebook.github.io/create-react-app/docs/deployment)

### `npm run build` fails to minify

This section has moved here: [https://facebook.github.io/create-react-app/docs/troubleshooting#npm-run-build-fails-to-minify](https://facebook.github.io/create-react-app/docs/troubleshooting#npm-run-build-fails-to-minify)

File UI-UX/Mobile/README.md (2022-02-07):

# Mobile UI-UX

## Home Page
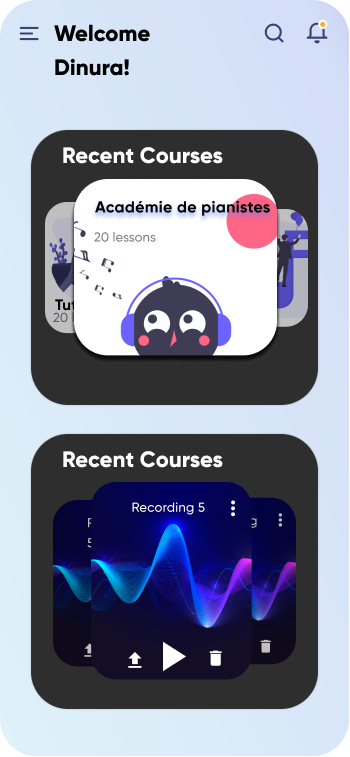
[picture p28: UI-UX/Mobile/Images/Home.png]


## Profile

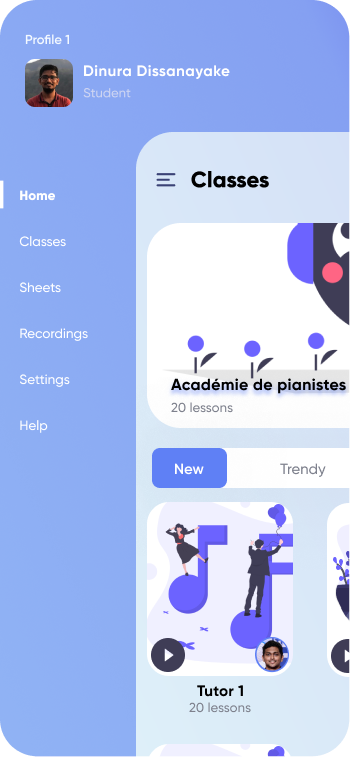
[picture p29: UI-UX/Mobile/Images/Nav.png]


## Classes

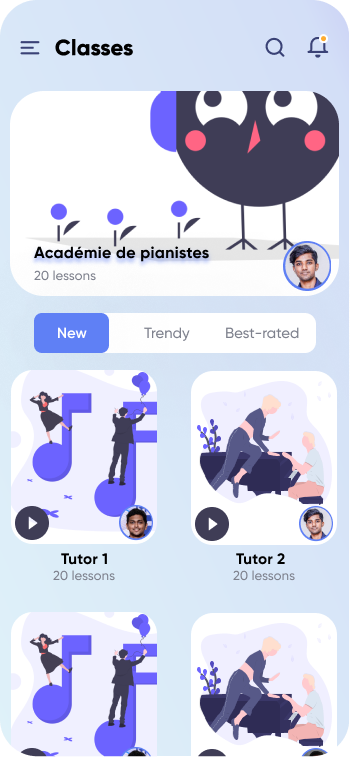
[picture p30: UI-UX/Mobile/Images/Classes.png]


## Tutor Profile
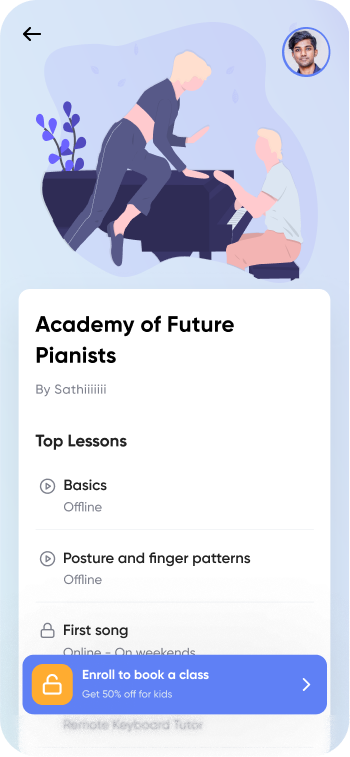
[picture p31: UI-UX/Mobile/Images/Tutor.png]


## Score Sheet Editor

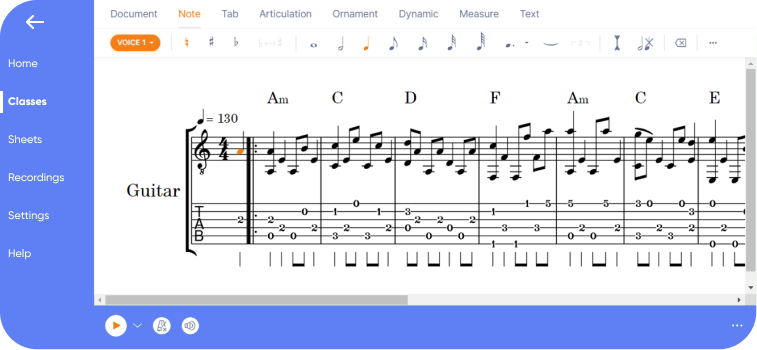
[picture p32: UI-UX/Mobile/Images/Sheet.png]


## Records



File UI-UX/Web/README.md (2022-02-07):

# WEB UI/UX

## Home Page


## Courses 


## Sheets

* All Score Sheets
  

* Play a Score Sheet
  

## Recordings


## Login


## Signup


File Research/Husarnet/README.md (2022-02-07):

# **Husarnet**



## **Introduction**

Husarnet is a global P2P network layer dedicated especially for robotic and IoT use cases with first class ROS support. It can be however used in much more areas such as, for example, automotive industry (V2V/V2X) or connecting distributed, critical resources like Smart Grids. It can be used in typical use cases for VPN networks as well.

## **Solution Architecture**

Husarnet solves these problems by having a peer-to-peer architecture. Central server **(Husarnet Base)** only helps in establishing connections over the Internet. LAN connections may be established without any Internet access.

Husarnet, in it's core, is one big, automatically routed, IPv6 network. Running Husarnet daemon creates a virtual network interface (hnet0) with an unique Husarnet IPv6 address and associated fc94::/16 route. If the permission system is disabled, any node can reach any other on its IPv6 fc94:... address.

The nodes are identified by their 112-bit IPv6 addresses. The IPv6 address is based on hash of the node public key. All connections are also authenticated by the IPv6 address.

## **Whitelisting**

Husarnet, by default, accepts connections only to nodes that are on its whitelist. Whitelist is simply a list of IPv6 addresses that are allowed to connect to your node (remember that the addresses are also cryptographic identifiers).

The whitelist can be managed either manually or via Websetup protocol. The Websetup protocol is used by the Husarnet Dashboard, which is a hosted service for managing Husarnet networks. The Websetup protocol is very simple - the Dashboard sends an UDP message over Husarnet containg the requested changes (e.g. whitelist-add or whitelist-rm). The message is authenticated with a shared secret and a separate IPv6 whitelist.

## **How connections are established**

connection-establishment

1. First, the Husarnet Client connects to the Husarnet Base Server (via TCP on port 443 and optionally UDP on port 5582) hosted by Husarnet company. Husarnet company runs multiple geographically distributed Husarnet Base Servers.  

2. Initially the encrypted data is tunnelled via the Husarnet Base Server.
3. The devices attempt to connect to local IP addresses (retrieved via the Base Server). This will succeed if they are in the same network or one of them has public IP address (and UDP is not blocked).
4. The devices attempt to perform NAT traversal assisted by the Base Server. This will succeed if NAT is not symmetric and UDP is not blocked on the firewall.
5. The devices send multicast discovery to the local network. This will succeed if the devices are on the same network (even if there is no internet connectivity or the Base Server can't be reached).
6. If peer-to-peer connection between devices is established, then user data goes directly between computers with Husarnet Client installed.

## **Role of a Husarnet Base Server**
<br>

- Storing all the connected clients' public IP addresses (and some other data)

- When establishing connection between two peers, exchanging their public IP addresses between them
- When P2P connection cannot be established between any pair of peers, transmitting all the data between them

## References

[Official Site](https://husarnet.com/)

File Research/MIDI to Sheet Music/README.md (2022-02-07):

# MIDI to Sheet Music

midi-to-sheet

Our product will often use MIDI messages to transmit data between the keyboard visualizer bar and the processing unit. But MIDI itself isn't interactive with most of the beginners. They'll be needing score sheets or sheet music to recognize what to play or, what is being played in his/her keyboard synthesizer. Therefor we'll be introducing a feature in a our web and mobile apps to convert these midi files to sheet music. We'll be using 
[BYVoid/MidiToSheetMusic](https://github.com/BYVoid/MidiToSheetMusic) opensource project to acheive this. </br></br>

[](https://padlet.com/sathiiii/RKT_Discussion) 

## Build

### Requirments :
* [Mono](https://www.mono-project.com/docs/getting-started/install/windows/)
* [Make](https://sourceforge.net/projects/mingw/files/Installer/mingw-get-setup.exe/download)

This is only deveoped for Windows

```bash
# Clone BYVoid/MidiToSheetMusic repository
C:\> git clone https://github.com/BYVoid/MidiToSheetMusic.git

# Go into the repository
C:\> cd MidiToSheetMusic

# Run makefile
C:\> make
```

This will create the executable file sheet.exe

Note : This project was done in 2013. Therefor the C# compiler in the makefile has to be changed from gmcs to mcs.

## Usage

### Windows :
```bash
C:\> sheet.exe <input>.mid <output>
```
### MacOS or Linux :
```bash
$ mono sheet <input>.mid <output>
```

Follow the given example,

## Download

[Source Code](https://github.com/BYVoid/MidiToSheetMusic/archive/master.zip)

[Executable File]()

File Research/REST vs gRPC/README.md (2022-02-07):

# REST vs gRPC



Oranges vs Apples? REST is an **architectural pattern**, but gRPC is a **framework** for implementing RPC APIs via HTTP/2.

Hmmmmmmmmmmmm?🤔

### _Our goal: Make the communication between ESP32s as fast as possible._

Two primary models for API design:
1. REST
2. RPC

Regardless of model, most modern APIs are implemented by mapping them in one way or another to the same HTTP protocol.

Most public APIs and many private distributed APIs **use HTTP as the transport**, at least in part because organizations are accustomed to dealing with the security issues of allowing HTTP traffic on ports 80 and 443.

## What is an API?

APIs stand for Application Programming Interfaces. These interfaces serve as a software intermediary that establishes **specific determinations and rules for applications to interact and talk to each other**.

An API is responsible for delivering a **response from a user to a system**, which in turn is sent back **from the system to the user**.



## APIs and Microservices

In a **monolithic application** (a platform consisting a database, server side and a client side), all the project's functionalities are included in a single codebase.

But a **microservice architecture** comprises several smaller services that communicate with each other using protocols like HTTP.

The component services that are part of the microservices architecture communicate and interact with each other through APIs. In other words, APIs allow all the services that are integrated into a microservice application **to connect and communicate**.

The most used architectural style is the REST API.

## REST: It's all about resources

REST by its very nature is **stateless**, and is built in such a way that any web service that is compliant with REST can interact in a stateless manner with textual **resource representations**.

This architectural model tends to follow the HTTP protocol. These operations are usually defined using GET, POST, PUT, and other HTTP methodologies as a matter of standardized interactions.

When using REST APIs, the response from the back-end data is passed to the clients through the JSON or XML messaging format.

### Advantages:

* Easy to understand.
* Web infrastructure is already built on top of HTTP.
* Tools for inspection, modification, testing are readily available.
* Loose coupling between client and server makes changes relatively easy.
* There are lot of frameworks in most of the widely used languages to create REST API’s.
* Http status codes are well defined and helps in identifying cause of problems.

### Disadvantages:

* While creating RESTful services, most of us follow a standard practice of writing client library and all we need to do is update client library whenever there is a change in api contracts.
* Streaming is difficult and its highly impossible in most of the languages.
* Duplex streaming is not possible.
* Hard to get multiple resources in single request.
* Need semantic versioning whenever the api contract needs to be changed.

Are these pain points are not there in gRPC? How does microservices talk to each other without a client library? The answer is google's **protobuf**.

## gRPC: It's all about APIs

gRPC owes its success to the employment of two techniques: using **HTTP/2** instead of HTTP/1.1 (but HTTP is not exposed to the API designer) and **protocol buffers** as an alternative to XML and JSON.

gRPC can use protocol buffers as both its **Interface Definition Language** (IDL) and as its underlying message interchange format.

RPC (Remote Procedure Call) is classic and the oldest API style currently in use. It uses **procedure calls** to request a service from a remote server **the same way you would request a local system** — via direct actions to the server (like SendUserMessages, LocateVehicle, addEntry). RPC is an efficient way to build APIs; RPC messages are lightweight and the interactions are straightforward.

gRPC is based around the idea of defining a service, specifying the methods that can be called remotely with their parameters and return types. On the server side, the server implements this interface and runs a gRPC server to handle client calls. On the client side, the client has a **stub** (referred to as just a client in some languages) that provides the same methods as the server.



gRPC clients and servers can run and talk to each other in a variety of environments - from servers inside Google to your own desktop - and can be written in any of gRPC’s supported languages.

### Protobuf / Proto

Google protobuf or proto is just a mechanism for serializing structured data. Proto is smaller, simpler, faster and language neutral.



1. In a .proto text file, a programmer defines a schema.
2. Using a protoc compiler, this file is then automatically compiled into any of the numerous supported languages like Java, C++, Python, Go, Dart, Objective-C, Ruby, and more.
3. At runtime, messages are compressed and serialized in binary format.

Protobufs offer great advantages over JSON and XML!

### gRPC benefits

* **Lightweight messages:** Depending on the type of call, gRPC-specific messages can be up to 30% smaller in size than JSON messages.

* **High performance:** By different evaluations, gRPC is 5, 7, and even 8 times faster than REST+JSON communication.

* **Built-in code generation:** gRPC has automated code generation in different programming languages including Java, C++, Python, Go, Dart, Objective-C, Ruby, and more.

* **More connection options:** While REST focuses on *request-response architecture*, gRPC provides support for *data streaming with event-driven architectures*: server-side streaming, client-side streaming, and bidirectional streaming.

* **Connection Pool:** We can create connection pool containing persistent connection to server through managed channels with states connected or idle.

### gRPC Weaknesses

* **Lack of maturity:** Compared to its peer GraphQL that has over 14k questions on StackOverflow, gRPC currently has a little under 4k. With minimal developer support outside of Google and not many tools created for HTTP/2 and protocol buffers, the community lacks information about best practices, workarounds.

* **Limited browser support:** Since gRPC heavily relies on HTTP/2, you can’t call a gRPC service from a web browser directly, because no modern browsers can access HTTP/2 frames. However, Google implemented [gRPC Web](https://github.com/grpc/grpc-web) client in JavaScript with an upcoming support for Python, Java, and more languages for browser support.

A web client sends a normal HTTP request to the proxy, which translates it and forwards it to the gRPC server.



Currently, not all gRPC features and advantages are available via web clients, although Google has a roadmap of upcoming features (like full streaming support and integration with Angular) that might ease the workload of using a proxy altogether.

* **Steeper learning curve:** Compared to REST and GraphQL, which primarily use JSON, it will take some time to get acquainted with protocol buffers and find tools for dealing with HTTP/2 friction.

* **No URL end points:** Can’t be tested with postman or curl to check the response.

* **No predefined status codes:** Creating custom status code may end up in conflicts.

## When to use gRPC vs REST?

* REST APIs may have their disadvantages, as we have discussed, but they remain the most known APIs for connecting microservices-based systems.
* gRPC may be used when operating an IoT system that requires light-weight message transmission such as the serialized Protobuf messages allow.
* gRPC should also be considered for mobile applications since they do not need a browser and can benefit from smaller messages, preserving mobiles' processors' speed.

## Conclusion

**Therefore, we have to options:**

1. Implement the backend using fully gRPC with the help of gRPC Web for the frontend support.
2. Use REST with protobuff instead of JSON/XML for the web clients and gRPC for communication between ESP32s.

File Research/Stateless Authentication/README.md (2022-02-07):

# Stateless Authentication: Persisting JWT Tokens

## Introduction

Authentication has been a stateful affair for a long time where all user details were stored server-side. This is known as **Stateful Authentication**. For complex architectures this can be limiting: getting data from the central store for every other operation can be troublesome.  Also, the server needs to keep the session’s state and data in its memory. 

If authentication and authorization were stateless each operation would carry all necessary data contained in them. This can be achieved using **tokens**.

**JSON Web Tokens (JWT)** are tokens generated by the server upon user authentication on a web application, and then sent to the client (usually a browser).



These tokens are then sent on every HTTP request, which allows the server to authenticate the user.

To ensure integrity, information contained in the token is signed by a **private key**, owned by the server. When the server gets the token back from the client, it just has to compare the signature sent by the client with the one it will generate with its private key. If the signatures are identical, the token is then valid.

## Anatomy of a JWT

According to RFC 7519, a JWT token is made of the following elements:

* A **Header** section, containing the algorithm used for the signature, as well as the type of token (**JWT** in our case). The whole thing is encoded in Base64.
* A **Payload** section, containing the token data, such as the user name, date of token generation or expiry date. All of that is written in JSON and also encoded in Base64.
* A **Signature** section, that is the result of Header and Payload, concatenated and then encrypted with the private key.

### Example of a JWT

**Header** section:
```
{
    “alg”: “HS256”,
    “typ”: “JWT”
}
```

**Payload** section:
```
{
    “iat”: 1480929282,
    “exp”: 1480932868,
    “name”: “Username”
}
```

A lot of information can be put into the second section (Payload), like the username, or the user’s rights on the application. The JWT specifications however clearly mention some keywords to be used, like “iat” (issued at = date and time of token generation, with a timestamp) or exp (expiry date).

## Refresh Tokens ✨

Refresh tokens server at least two purposes: first, the refresh token is a kind of 'proof' that an OAuth2 Client has already received permission from the user to access their data, and so can request a new access token again without requiring the user to go through the whole OAuth2 flow. Second, it helps increase the whole flow of security when compared with a long lived access token. Refresh tokens can be used to make the user experience more seamless, as the user doesn’t have to go through the whole OAuth2 flow again.

## Storing a JWT in the browser

Storing a token in client-side storage can be vulnerable to attacks. Therefore, if someone wants to completely prevent cross-site attacks, the best way is to store the tokens in memory (redux storage). But that'll reduce the quality of the user experience because the user will have to re-authenticate (login) every time the page is refreshed (redux storage is not persistent). In a web application like ours (an e-learning platform), this is bad.

Therefore, we have to somehow store the token in the browser such that the vulnerabilities that they can be exploited are quite unlikely. The following is an analysis and **our thinking process** of finding different ways to store a token in the client-side:

There are two ways to store data in a browser:

1. Local Storage (or Session Storage - which is the same as the local storage but is deleted when the session ends).
2. Cookies.

But they both have the following vulnerabilities:

* **Local storage** *is* vulnerable to **XSS** (Cross-Site-Scripting) attacks: If a malicious third party is able to inject JS into our web application, they can make requests to our API using the tokens and then collect the results on their servers and/or perform actions while acting as the user (deleting/updating data etc.) Basically, **if someone has JS in our app, they can do anything and everything the user is authorized to do**.

* **Local storage** *isn't* vulnerable to **CSRF** (Cross-Site-Request-Forgery) attacks: CSRF works by making a request to the API from another domain. But local storage is only accessible from the same domain (i.e. if our app forte.com has saved data in the local storage, then maliciousapp.com can't access them).

* **Cookies** *are* vulnerable to **XSS** attacks: Cookies can be made secure for XSS attacks with all the correct flags (httpOnly, secure, sameSite) so that injected JS can't access them. However, even with those flags, if a third party had successfylly inject JS into our app, they could still make requests to the API acting as they are the authenticated user. This is because even though they can't access the tokens - the cookie is still sent with every request. So the API will see that the token in the cookie is valid and respond to the request. At this point the attacker can perform as many data mutations as they want and they can make GET requests then send the responses to their own server using some basic javascript. It doesn't take a particulary smart hacker to cook up a basic JS script that does this - essentially turning users' browsers into proxies for malicious requests.

* **Cookies** *are* vulnerable to **CSRF** attacks: Cookies are intrinsically vulnerable to CSRF because they are automatically sent with each request. This allows attackers to easily craft malicious requests that lead to CSRF. Although the attacker cannot obtain the response body or the cookie itself, they can perform actions with the victim's elevated rights as mentioned above. It is important to note that HttpOnly and sensible CORS policies cannot prevent CSRF form-submit attacks and using cookies require a proper CSRF mitigation strategy.

Therefore, comparing the two vulnerabilities, we can see that **local storage is relatively more secure than cookies**.

However, before we proceed to finding a secure way for token storage, we have to keep in mind that just in case the option of using **redux states** is also there if we can somehow find a solution for making the tokens persistent.

### Strategy - 1: Trying to store the tokens in the browser using local storage and cookies with a secure strategy

We saw this strategy on [this](https://www.reddit.com/r/reactjs/comments/cubfsa/local_storage_vs_cookies_authentication_tokens/) subreddit. It's a simple solution that utilizes both local storage and cookies.

The idea is to store the refresh token and access token in httpOnly Secure cookies.

Then use another token in the authentication called the **CSRF Token**. The API should require this token to be in every request. Then, even if the request had a valid access token, the API wouldn't respond unless it was accompanied by a valid CSRF token.

The CSRF token has to be stateless. We can make the CSRF token a hash of the refresh token and then include in the JWT payload.

This way, on routes that require the refresh token (/auth/refreshToken), the API can verify that the CSRF token is valid by just hashing the refresh token and comparing it to the CSRF token in the cookie sent with the request.

On all the other routes that require just the access token, the API can compare the CSRF token in the JWT payload with the CSRF token in the cookie passed in the request.

**Can't an attacker hash the refreshToken themselves to generate a valid CSRF?** -> No, because the refreshToken will be stored in a Secure HttpOnly cookie - JS can't see it.

**Can't an attacker just look at the JWT claims to get the valid CSRF** -> The Access Token is also stored as a Secure HttpOnly Cookie, JS can't see it.

This CSRF token will be stored in LocalStorage (rendering CSRF attacks ineffective since they rely solely on cookies).

However, the above strategy doesn't totally prevent third parties from making requests to the API and performing actions as the user because an attacker doesn't need to have access to the tokens in order to make requests to the API. An attacker can exploit the fact that the Refresh and Access tokens are stored in cookies (so they are automatically sent in every request) and they can get the CSRF token by querying LocalStorage.

Note that the new **SameSite cookie** spec which is getting increased support in most browsers will make Cookie based approaches safe from CSRF attacks.

### Strategy - 2: Proceeding with redux states

As discussed earlier, the access token stored in redux storage will be nullified when the user switches between tabs or refreshes the page. Therefore, we have to find a way to make the tokens persistent.

The idea is to use refresh tokens!



1. The user logs in with a login API call.
2. Server generates JWT Token and refresh_token.
3. Server sets a **HttpOnly cookie with refresh_token**. jwt_token and jwt_token_expiry are returned back to the client as a JSON payload.
4. The jwt_token is stored in memory.
5. A countdown to a future **silent refresh** is started based on jwt_token_expiry.

**Silent refresh** is the way to refresh the access token before the short lived access token expires without the user having to log in again.

Because client side Javascript can't read or steal an HttpOnly cookie, this is a little better at mitigating XSS than persisting it as a normal cookie or in localstorage.

This is safe from CSRF attacks, because even though a form submit attack can make a /refresh_token API call, the attacker cannot get the new JWT token value that is returned.



1. Call /refresh_token endpoint
2. Server will read httpOnly cookie and if it finds a valid refresh_token, then...
3. ...the server returns a new jwt_token and jwt_token_expiry to the client and also sets *a new refresh token* cookie via  Set-Cookie header.

Refresh tokens have a long lifetime. If they are valid and not expired, clients can obtain new access tokens. This long lifetime may lead to vulnerability for protected resources. That's why when a new access token is requested by calling the /refresh_token endpoint, the old refresh token is invalidated and a new one is sent. This is known as **refresh token rotation**. The purpose of **refresh token rotation** is to eliminate the vulnerability risk posed by long-lasting refresh tokens.

Note that **using refresh tokens make the authentication process stateful** since they have to be stored in the server database. But we might have to compromise that in order to make the user experience better and to make authentication secure.

However with the above strategy, the session will still be lost if the user closes the tab or refreshes the page.

**Refresh tokens to the saving! ✨**

Since refresh tokens are persisted as an httpOnly cookie, we can use them to fetch a new JWT token for a new session when the user logged out of their current session by closing the tab or refreshing the page. Now that the user visits the app again, let's see what the flow looks like:



1. If we see that we don't have a JWT in redux memory, then we trigger the silent refresh workflow.
2. If the refresh token is still valid (or hasn't been revoked), then we get a new JWT and we're good to go!

In case our refresh token expires (say the user comes back to the app after a really long time), or gets revoked (because of a "force logout", say) the client will get 401 error for an unauthorized refresh_token. Another case might just be that we don’t have any refresh_token in the first place, in which case we'll also get an error from our /refresh_token endpoint and we will redirect the user to the login screen.

## Refresh Token Reuse Detection

Refresh token reuse detection is a mechanism that supports refresh token rotation. When an access token expires, the client gets a new set of tokens (access and refresh token) using a refresh token. Then, the identity provider immediately invalidates the previous refresh token.

If the identity provider detects the use of that invalidated refresh token, it immediately invalidates all the refresh and access tokens making the client authenticate using login credentials again. This mechanism prevents our app from malicious attacks when there is a leakage of tokens.

## Force Logout

Now that are users are logged in forever and stay logged in across sessions, there's a new problem that we need to worry about: Force logout or, logging out of all sessions and devices.

The refresh token implementations from the sections above, show us that we can persist sessions and stay logged in.

In this case, a simple implementation of "force logout" is asking the auth server to invalidate all refresh tokens associated for a particular user.

This is primarily an implementation on the auth server backend, and doesn't need any special handling on the client.

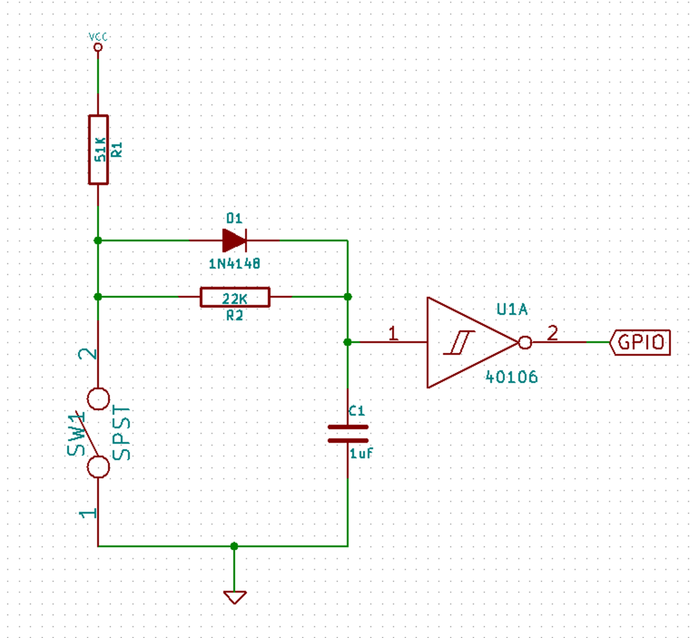
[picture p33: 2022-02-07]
Hardware/Schematics/debounce_rc.png

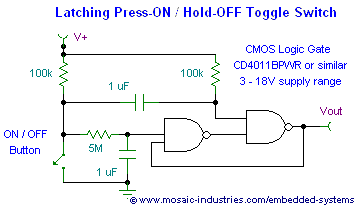
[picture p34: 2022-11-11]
Hardware/Schematics/Power Supply/latch.png

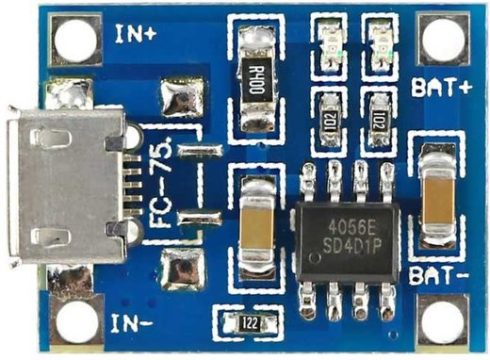
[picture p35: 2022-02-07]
Hardware/Schematics/Power Supply/TP4056.jpg

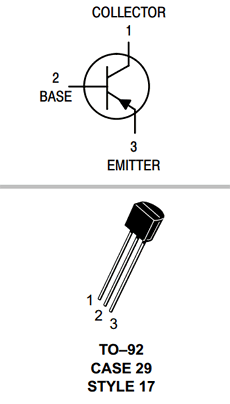
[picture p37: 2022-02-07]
Hardware/Schematics/BC212.gif

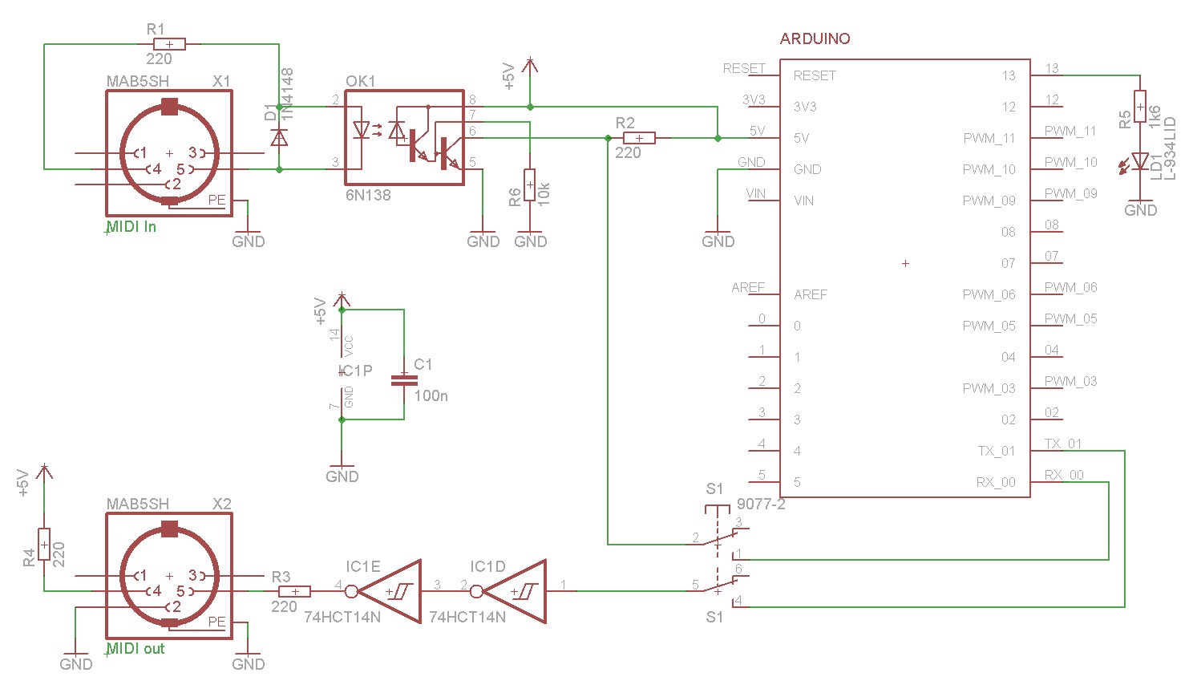
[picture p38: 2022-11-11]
Hardware/Schematics/MIDI Interface/MIDI IO Shield.jpg

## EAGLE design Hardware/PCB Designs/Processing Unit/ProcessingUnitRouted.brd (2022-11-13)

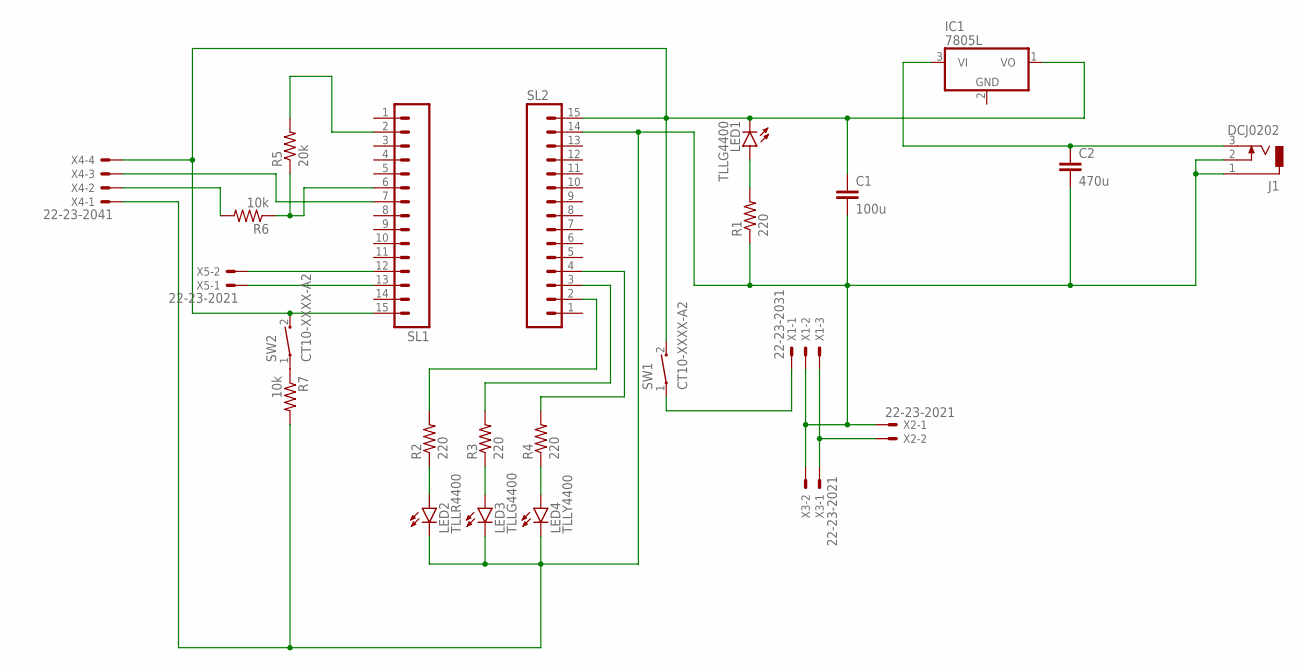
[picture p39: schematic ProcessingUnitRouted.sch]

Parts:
C1: 100u; C025-025X050
C2: 470u; C025-025X050
IC1: 7805L; TO92
J1: DCJ0202
LED1, LED3: TLLG4400; LED3MM
LED2: TLLR4400; LED3MM
LED4: TLLY4400; LED3MM
R1, R2, R3, R4: 220; 0204/7
R5: 20k; 0204/7
R6, R7: 10k; 0204/7
SL1, SL2: M15; 15P
SW1, SW2: CT10-XXXX-A2
X1: 22-23-2031
X2, X3, X5: 22-23-2021
X4: 22-23-2041

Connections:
unnamed: SL1.13, X5.1
unnamed: R5.2, SL1.2
unnamed: LED1.A, R1.2
unnamed: C2.1, IC1.3 (VI), J1.3
unnamed: SW1.1, X1.1
unnamed: LED2.A, R2.1
unnamed: X1.3, X2.2, X3.1
unnamed: R2.2, SL2.2
unnamed: R3.2, SL2.3
unnamed: R4.2, SL2.4
unnamed: LED3.A, R3.1
unnamed: LED4.A, R4.1
unnamed: C1.2, C2.2, J1.1, J1.2, LED2.K (C), LED3.K (C), LED4.K (C), R1.1, R7.2, SL2.14, X1.2, X2.1, X3.2, X4.1
unnamed: R5.1, R6.1, SL1.6
unnamed: R7.1, SW2.1
unnamed: R6.2, X4.2
unnamed: SL1.7, X4.3
unnamed: C1.1, IC1.1 (VO), LED1.K (C), SL1.15, SL2.15, SW1.2, SW2.2, X4.4
unnamed: SL1.12, X5.2

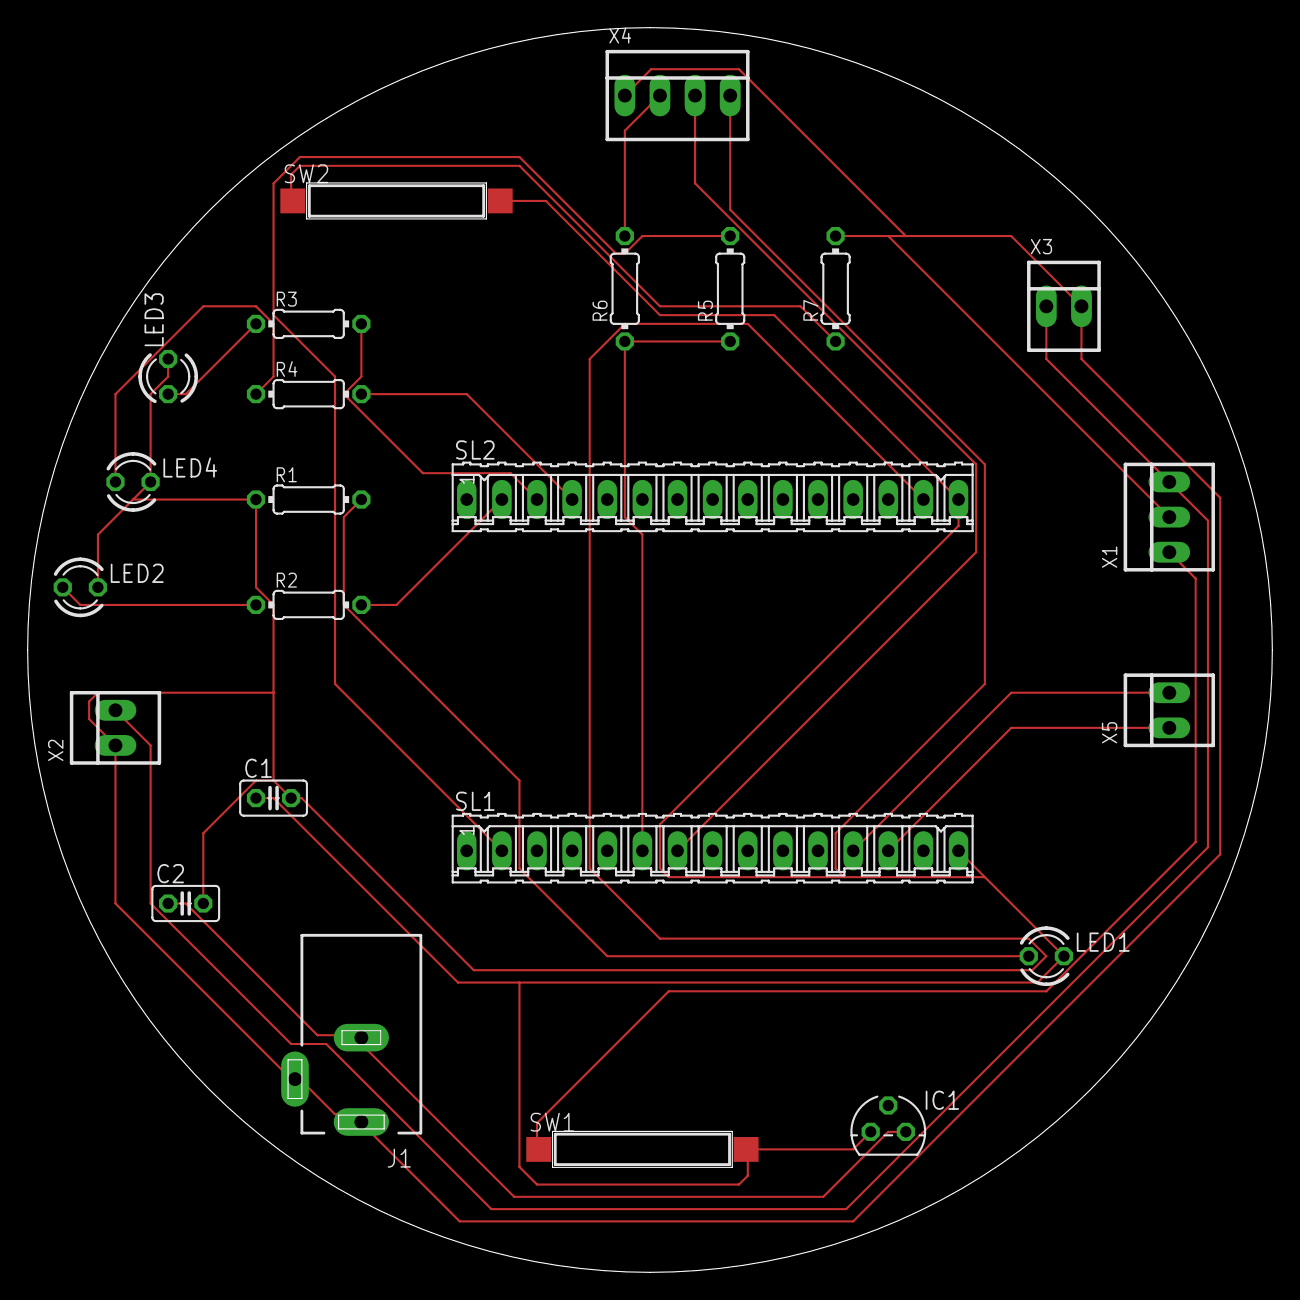
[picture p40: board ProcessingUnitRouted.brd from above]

Board: 2 copper layers, 90.0 x 90.0 mm, 24 parts (0 on the bottom side), 19 nets.

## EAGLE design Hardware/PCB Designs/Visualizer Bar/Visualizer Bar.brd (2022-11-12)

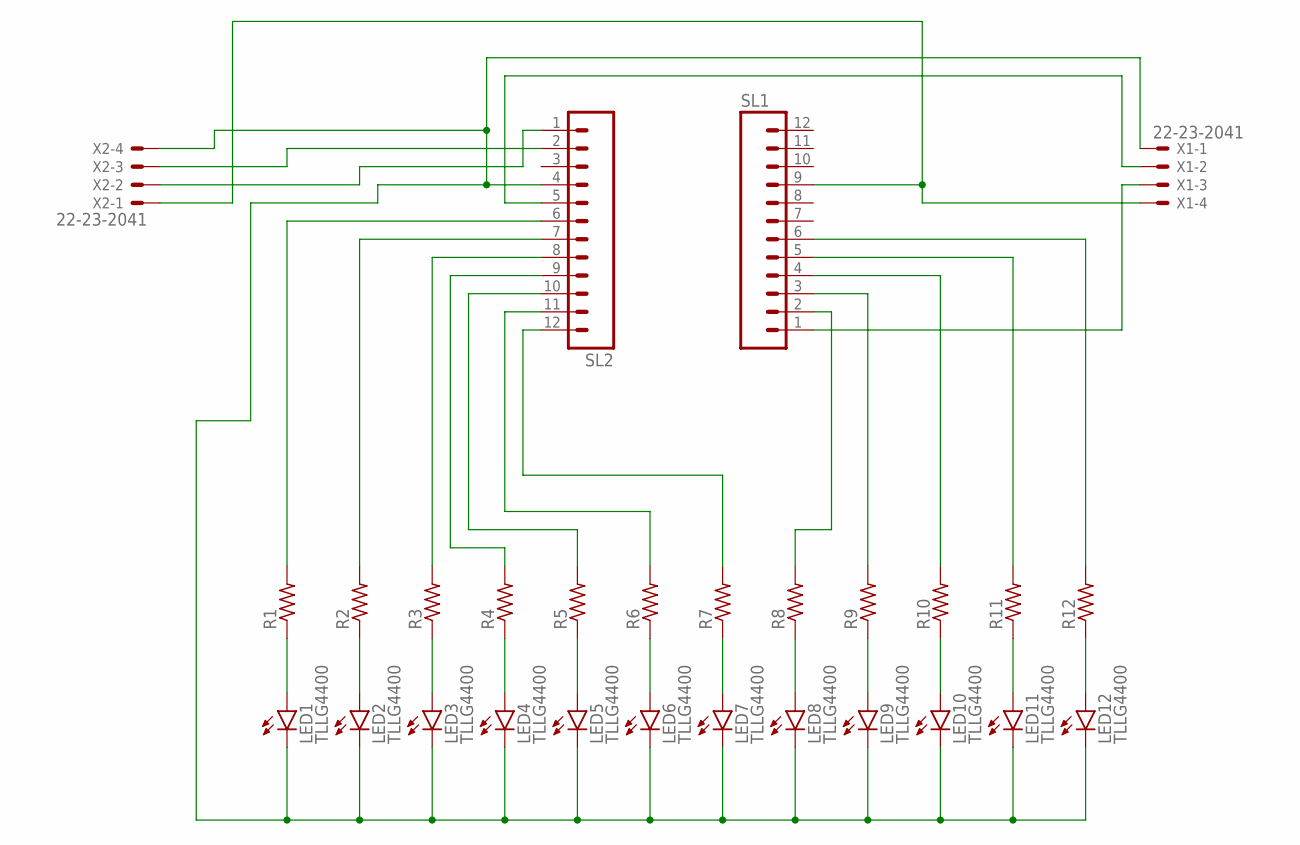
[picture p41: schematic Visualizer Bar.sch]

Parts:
LED1, LED2, LED3, LED4, LED5, LED6, LED7, LED8, LED9, LED10, LED11, LED12: TLLG4400; LED3MM
R1, R2, R3, R4, R5, R6, R7, R8, R9, R10, R11, R12: R-US_0204/5; 0204/5
SL1, SL2: M12; 12P
X1, X2: 22-23-2041

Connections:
unnamed: R6.2, SL2.11
unnamed: R4.2, SL2.9
unnamed: R3.2, SL2.8
unnamed: R5.2, SL2.10
unnamed: R2.2, SL2.7
unnamed: SL1.1, X1.3
unnamed: R12.2, SL1.6
unnamed: R11.2, SL1.5
unnamed: R10.2, SL1.4
unnamed: R9.2, SL1.3
unnamed: R8.2, SL1.2
unnamed: R7.2, SL2.12
unnamed: LED1.A, R1.1
unnamed: LED2.A, R2.1
unnamed: LED3.A, R3.1
unnamed: LED4.A, R4.1
unnamed: LED5.A, R5.1
unnamed: LED6.A, R6.1
unnamed: LED7.A, R7.1
unnamed: LED8.A, R8.1
unnamed: LED9.A, R9.1
unnamed: LED10.A, R10.1
unnamed: LED11.A, R11.1
unnamed: LED12.A, R12.1
unnamed: R1.2, SL2.6
unnamed: SL2.5, X1.2
unnamed: LED1.K (C), LED2.K (C), LED3.K (C), LED4.K (C), LED5.K (C), LED6.K (C), LED7.K (C), LED8.K (C), LED9.K (C), LED10.K (C), LED11.K (C), LED12.K (C), SL2.4, X1.1, X2.4
unnamed: SL1.9, X1.4, X2.1
unnamed: SL2.2, X2.3
unnamed: SL2.1, X2.2

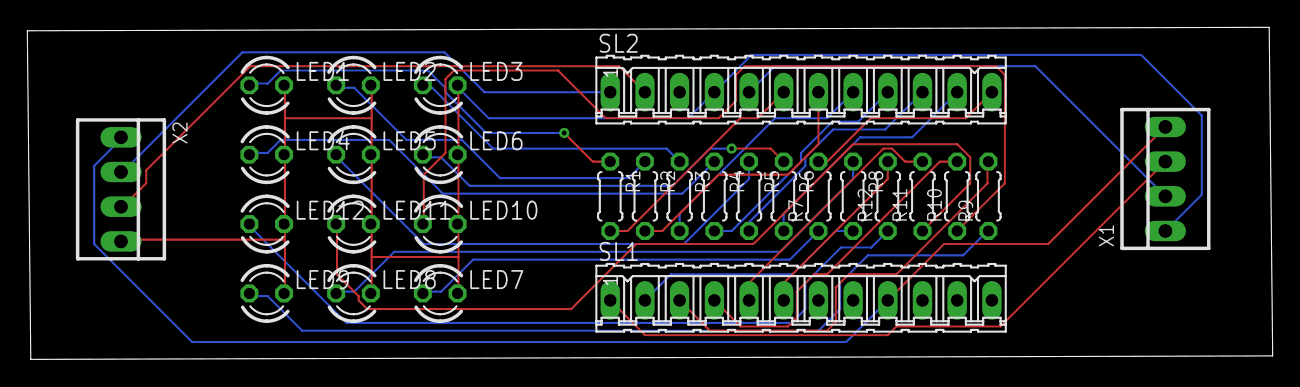
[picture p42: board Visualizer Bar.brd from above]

Board: 2 copper layers, 91.2 x 24.3 mm, 28 parts (0 on the bottom side), 30 nets.

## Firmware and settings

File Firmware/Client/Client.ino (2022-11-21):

/*
 * Receiver
 */

#include <esp_now.h>
#include <WiFi.h>

#define ONBOARD_LED  2

#define MIDI_BAUD 31250
#define MAX_BAUD 115200

#define RCV_MSK 0xF
#define SEND_MSK 0xF0
#define SEND_OFFSET 4
#define ACTION_MSK 0x3
#define ACTION_OFFSET 8
#define ACTION_OFFSET2 2
#define CTRL_MSK 0xFC
#define CTRL_OFFSET 10
#define CTRL_OFFSET2 8

#define UNK_ID 0xF
#define HOST_ID 0
// These bytes may never occur in a packet, so they are used to indicate the start and end of a packet.
#define START_BYTE 0x7E
#define END_BYTE 0x7F

#define DEV_NOTIFY 0
#define DEV_DISCOVERY 1
#define HOST_NOTIFY 2
#define CONTROL 3

#define CONNECTED 1

uint32_t rcv_buff[4], wifi_rcv_buff[4];
bool incoming = false;
bool wifi_incoming = false;

uint32_t createPacket(uint32_t rec_id, uint32_t send_id, uint32_t action, uint32_t ctrl) {
  return rec_id | (send_id << SEND_OFFSET) | (action << ACTION_OFFSET) | (ctrl << CTRL_OFFSET);
}

uint32_t deviceDiscovery() {
  return createPacket(UNK_ID, HOST_ID, DEV_DISCOVERY, 0);
}

int j = 0;

// callback function that will be executed when data is received
void OnDataRecv(const uint8_t * mac, const uint8_t *incomingData, int len) {
  uint8_t b = *incomingData;
  if (b == START_BYTE) {
        wifi_incoming = true;
        j = 0;
        return;
      }
      if (b == END_BYTE) {
        wifi_incoming = false;
        j = 0;
        return;
      }
      if (!wifi_incoming) return;
      wifi_rcv_buff[j++] = b;
      if (j == 4) {
        Serial.print(wifi_rcv_buff[3], HEX);
        Serial.print(" ");
        Serial.print(wifi_rcv_buff[2], HEX);
        Serial.print(" ");
        Serial.print(wifi_rcv_buff[1], HEX);
        Serial.print(" ");
        Serial.print(wifi_rcv_buff[0], HEX);
        Serial.println();
      }
}
 
void setup() {
  
  // Initialize Serial Monitor
//  Serial.begin(115200);
  Serial.begin(9600);
  Serial2.begin(MIDI_BAUD);
  
  // Set device as a Wi-Fi Station
  WiFi.mode(WIFI_STA);

  // Init ESP-NOW
  if (esp_now_init() != ESP_OK) {
    Serial.println("Error initializing ESP-NOW");
    return;
  }
  
  // Once ESPNow is successfully Init, we will register for recv CB to
  // get recv packer info
  esp_now_register_recv_cb(OnDataRecv);
}

// i -> visualizer bar communication byte counter
// j -> wifi com byte counter
int i = 0;

bool alt = false;

void loop() {
  if (Serial2.available()) {
      char b = Serial2.read();
      // Serial.println(b, HEX);
      if (b == START_BYTE) {
        incoming = true;
        i = 0;
        return;
      }
      if (b == END_BYTE) {
        incoming = false;
        i = 0;
        return;
      }
      if (!incoming) return;
      rcv_buff[i++] = b;
      if (i == 4) {
        // Serial.println(packet, HEX);
        // **** TESTING THE PACKET ****
        // Serial.print(rcv_buff[3], HEX);
        // Serial.print(" ");
        // Serial.print(rcv_buff[2], HEX);
        // Serial.print(" ");
        // Serial.print(rcv_buff[1], HEX);
        // Serial.print(" ");
        // Serial.print(rcv_buff[0], HEX);
        // Serial.println();
        uint32_t rec_id = rcv_buff[3] & RCV_MSK;
        uint32_t send_id = (rcv_buff[3] & SEND_MSK) >> SEND_OFFSET;
        uint32_t action = rcv_buff[2] & ACTION_MSK;
        uint32_t ctrl = ((rcv_buff[2] & CTRL_MSK) >> ACTION_OFFSET2) | (rcv_buff[1] << CTRL_OFFSET2);
      if (action == DEV_NOTIFY && ctrl == CONNECTED) {
        Serial.println("Visualizer bar detected!");
        Serial.println("Sending device discovery packet...");
        uint32_t packet = deviceDiscovery();
        Serial2.write(START_BYTE);
        Serial2.write((uint8_t) (packet >> 24));
        Serial2.write((uint8_t) (packet >> 16));
        Serial2.write((uint8_t) (packet >> 8));
        Serial2.write((uint8_t) packet);
        Serial2.write(END_BYTE);
      }
      else if (action == HOST_NOTIFY && ctrl == CONNECTED) {
        Serial.println("Visualizer block-" + String(send_id) + " connected!");
      }
      }
    }
}

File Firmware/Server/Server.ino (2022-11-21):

/*
  Sender
*/

#include <esp_now.h>
#include <WiFi.h>


// These bytes may never occur in a packet, so they are used to indicate the start and end of a packet.
uint8_t START_BYTE =  0x7E;
uint8_t END_BYTE =  0x7F;

// REPLACE WITH YOUR RECEIVER MAC Address
// 08:3A:F2:50:BF:FC esp 32 3.3 board MAC
uint8_t broadcastAddress[] = {0x08, 0x3A, 0xF2, 0x50, 0xBF, 0xFC};

uint32_t data1 = 0xABCDE091;



esp_now_peer_info_t peerInfo;

// callback when data is sent
void OnDataSent(const uint8_t *mac_addr, esp_now_send_status_t status) {
  Serial.print("\r\nLast Packet Send Status:\t");
  Serial.println(status == ESP_NOW_SEND_SUCCESS ? "Delivery Success" : "Delivery Fail");
}
 
void setup() {
  // Init Serial Monitor
  Serial.begin(115200);

  // Set device as a Wi-Fi Station
  WiFi.mode(WIFI_STA);

  Serial.print("Task1 running on core ");
  Serial.println(xPortGetCoreID());

  
  // Init ESP-NOW
  if (esp_now_init() != ESP_OK) {
    Serial.println("Error initializing ESP-NOW");
    return;
  }

  // Once ESPNow is successfully Init, we will register for Send CB to
  // get the status of Trasnmitted packet
  esp_now_register_send_cb(OnDataSent);
  
  // Register peer
  memcpy(peerInfo.peer_addr, broadcastAddress, 6);
  peerInfo.channel = 0;  
  peerInfo.encrypt = false;
  
  // Add peer        
  if (esp_now_add_peer(&peerInfo) != ESP_OK){
    Serial.println("Failed to add peer");
    return;
  }

}


 
void loop() {
  
    esp_err_t result = esp_now_send(broadcastAddress, &START_BYTE, sizeof(START_BYTE));
    uint8_t temp = data1 >> 24;
    result = esp_now_send(broadcastAddress, (const uint8_t*)(&temp), sizeof(uint8_t));
    temp = data1 >> 16;
    result = esp_now_send(broadcastAddress, (const uint8_t*)(&temp), sizeof(uint8_t));
    temp = data1 >> 8;
    result = esp_now_send(broadcastAddress, (const uint8_t*)(&temp), sizeof(uint8_t));
    temp = data1;
    result = esp_now_send(broadcastAddress, (const uint8_t*)(&temp), sizeof(uint8_t));
    result = esp_now_send(broadcastAddress, &END_BYTE, sizeof(END_BYTE));
        
    
     
    if (result == ESP_OK) {
      Serial.println("Sent with success");
    }
    else {
      Serial.println("Error sending the data");
    }
    delay(2000); 
  
}

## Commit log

2022-11-11 Update schematics + firmware testing codes
2022-11-12 Added viaulizer Bar PCB eagle files
    [Visualizer Bar.brd, Visualizer Bar.sch]
2022-11-13 File location changes
    [Visualizer Bar.brd, Visualizer Bar.sch]
2022-11-13 Added the processing unit pcb designs
    [ProcessingUnit.brd, ProcessingUnit.sch, ProcessingUnitRouted.brd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]
